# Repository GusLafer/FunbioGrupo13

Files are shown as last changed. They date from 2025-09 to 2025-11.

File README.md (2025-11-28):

Damas y caballeros, sean bienvenidos al respositorio del grupo 12 del curso "Fundamentos de Biodiseño" :3
# Fundamentos de Biodiseño Grupo 12
Integrantes:
* CASTILLO MAYTA, ANYELO ARMANDO, anyelo.castillo@upch.pe
* CASTILLO ZAPATA, CRISTHIAN LEONARDO, cristhian.castillo@upch.pe
* CERNA ACOSTA, JULIO ANDRES julio.cerna@upch.pe
* CUENTAS FERREÑAN, BONNIE CAMILA, bonnie.cuentas@upch.pe
* FERNANDEZ BACA LARA, GUSTAVO RODOLFO, gustavo.fernandez.baca@upch.pe
* GARCIA ROJAS, KARLA EMILY, karla.garcia.r@upch.pe

Logo del grupo

## Tabla de contenidos:
* Ficha de enfermedad
  * Nombre de la enfermedad: Esclerosis Lateral Amiotrófica
  * Sistema afectado: Neurologico
  * Breve descripcion: Enfermedad que se caracteriza por la degeneracion de las neuronas motoras, lo que causa debilidad en diferentes musculos.
* Factores y analisis de la enfermedad
* Prevención, diagnóstico, tratamiento y monitoreo

  Hay un unico medicamento, el riluzol, que demostro retrasar el uso de ventilacion mecanica.

   Entre sus metodos de diagnostico estan:

  * Neurofisiologia: por medio de la electromiografía con neuroconducciones se logran detectar alteraciones en la neurona Motora Inferior.  
  * Neuroimagenes: 
  * Estudios geneticos: 
  * Laboratorios: 
* Reflexión ingenieril:
  
  El prototipo consiste en una palanca mecánica adaptable que se acopla directamente al eje de la rueda de la silla de ruedas. Está diseñada específicamente para un paciente tetrapléjico con movilidad muy limitada en los brazos, que no puede alcanzar ni accionar el sobre-aro convencional.
  
* Bibliografia
  
  Zapata-Zapata, C., Franco-Dáger, E., Solano-Atehortúa, J., & Ahunca-Velásquez, L. (2016). Esclerosis lateral amiotrófica: actualización. IATREIA, 29(2). https://doi.org/10.17533/udea.iatreia.v29n2a08
  Ingre, C., Roos, P. M., Piehl, F., Kamel, F. y Fang, F. (2015). Factores de riesgo para la esclerosis lateral amiotrófica. Epidemiología clínica, 7, 181–193. https://doi.org/10.2147/CLEP.S37505

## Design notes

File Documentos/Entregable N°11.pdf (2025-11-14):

ENTREGABLE N° 11: INTEGRACIÓN HARDWARE - SOFTWARE - MANUFACTURA DIGITAL

1. Verificación del software
Funcionalidad | Cumplimiento | Observaciones/mejoras
SÍ | NO
La señal de encendido debe iniciar el sistema del microcontrolador y los demás componentes, incluido el LED de encendido | SI | | Como mejora, se podría usar un interruptor fácil de manipular por el usuario.
Se lee correctamente la posición del switch de cambio de sentido con 3 terminales | SI | | Asegurar que los cables estén bien sujetos.
El servomotor se mueve acorde a lo indicado con el switch de cambio de sentido. | SI | | El servo cumple con las funciones que se le asignaron correctamente.
Cuando se detecta una batería menor a 20% debe mandar una señal que encienda el LED de carga. | | NO | Se debe ajustar la lectura de voltaje para que se pueda encender un led por batería baja.
2. Verificación de hardware
Preguntas clave:
- ¿Cuánto peso debe tener el dispositivo?
El dispositivo no debe superar los 2 kg, para no agregar carga excesiva a la silla, ni dificultar el movimiento del usuario.
- ¿Qué altura y posición debe tener la palanca y el mango?
La palanca es ajustable, de modo que puede colocarse a la altura más cómoda para cada usuario sin generar esfuerzo adicional.
- ¿El dispositivo permite desplazarse en silla de ruedas?
Si. La palanca y el mecanismo están diseñados para asistir el avance de la silla de ruedas mediante un sistema de tracción controlado por servo.
- ¿Cuánta fuerza máxima debe ejercer el paciente para movilizarse?
La fuerza requerida no debe superar aproximadamente los 20N.
- ¿Dónde y cómo se debe acoplar el dispositivo en la silla de ruedas?
El dispositivo se acciona desde el eje de la rueda, mediante un mecanismo tipo ratchet asistido por un servo, que convierte el movimiento de la palanca en avance sin retroceso.
- ¿Dónde se deben ubicar los interruptores para que sean accesibles?
El interruptor debe colocarse cerca del mango de la palanca, accesible sin que el usuario deba perder el control.
- ¿Qué señales visuales debe brindar el dispositivo?
Es un prototipo, en un futuro se le incorporarán leds para que el usuario pueda tener señales visuales.
- ¿Cuánto tiempo debe durar la batería?
La batería debe permitir mínimo 2 horas continuas de uso antes de requerir carga

Esta debe tener por lo menos una duración de 2 horas

Requerimiento de diseño | Cumplimiento | Resultados/mejoras
SÍ | NO
El dispositivo pesa menos de 1 kg | | NO | Es un prototipo así que se podría mejorar mediante materiales y componentes más ligeros.
La altura de la palanca y la posición del mango son regulables basado en la ergonomía del paciente. | SI | | Se puede mejorar la rigidez para evitar pequeños movimientos laterales.
El mango es suave y cómodo para el usuario | | No | El dispositivo es un prototipo por lo cual no se priorizo que el mango sea suave sino el funcionamiento del sistema ratchet
El sistema ratchet permite el giro de la rueda en un sentido y el retroceso de la palanca en el otro | SI | | Se puede optimizar el servo Horn para un cambio de sentido más cómodo.
El usuario debe ejercer menos de 50 N para remar la silla mediante la palanca | SI | | El esfuerzo requerido está dentro del rango adecuado para el usuario.
El encaje del dispositivo se acopla con firmeza y estabilidad al eje de una silla de ruedas estándar | | No | El dispositivo por el momento no entra por completo al eje de la silla de ruedas, pero esta si puede mover la rueda, se busca regular la pieza para que esta se acople por completo en el eje de la rueda.
El dispositivo presenta un interruptor de encendido y uno de cambio de sentido del desplazamiento | SI | | El dispositivo cuenta con estas funciones aunque todavía falta colocar los dispositivos en lugares óptimos.
Los interruptores se encuentran cerca del mango para facilitar el acceso | | No | Estos por el momento no se encuentran en la parte del mango.
Los interruptores son fácilmente manipulables sin necesidad de movimientos finos. | | No | Se busca optimizar los interruptores para que el usuario pueda presionar los interruptores con facilidad
Hay leds ubicados en zonas visibles que indican el ON/OFF del dispositivo y cuando la batería debe ser recargada (<20%) | | No | Por el momento no se colocaron ciertos leds, ya que lo principal que se busco fue el correcto funcionamiento del sistema ratchet

La duración de la batería debe ser mínimo de 2 horas | | No | Optimizar el consumo de batería
La batería es recargable y presenta un puerto de carga accesible para su uso. | Si | | Mayor capacidad de batería

Fotos:

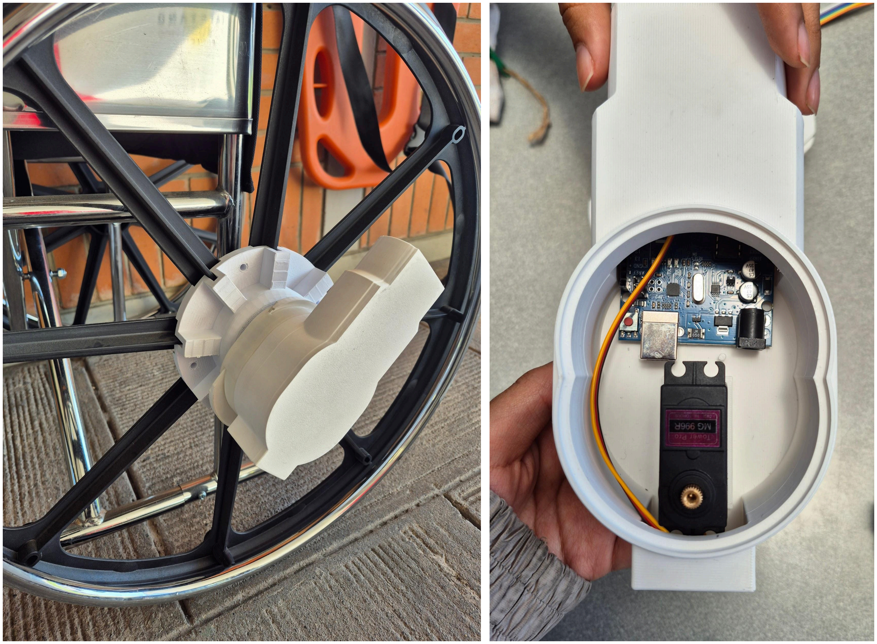
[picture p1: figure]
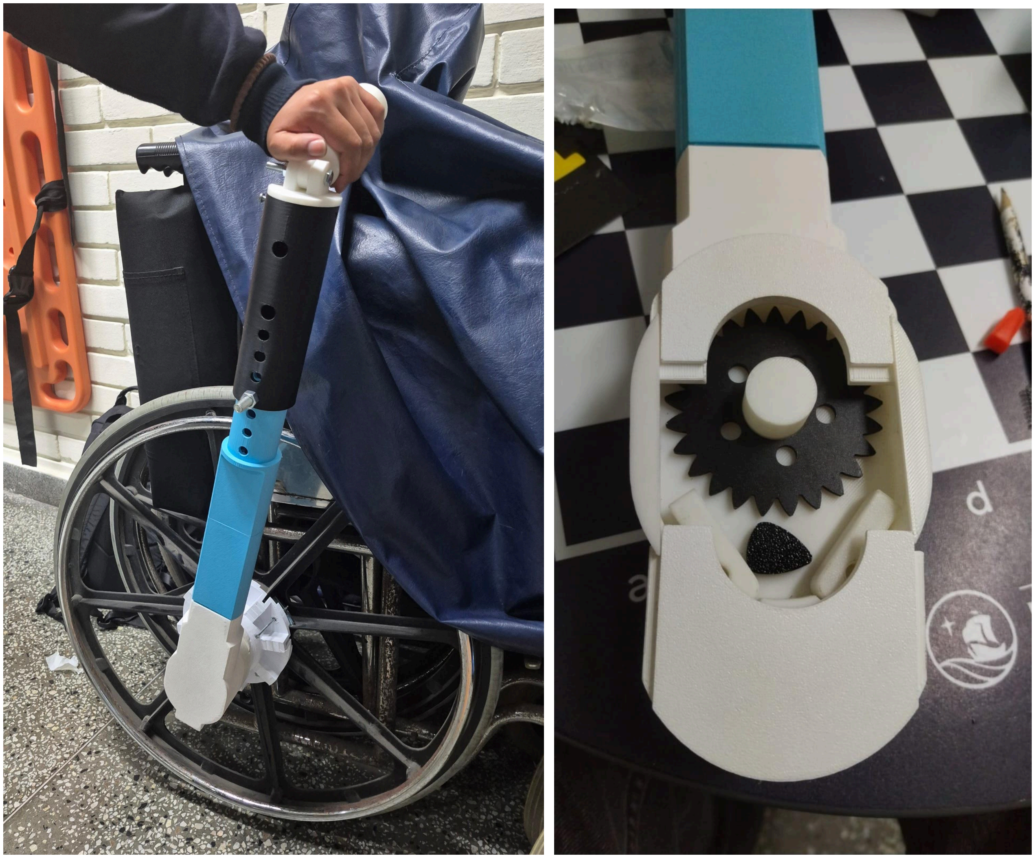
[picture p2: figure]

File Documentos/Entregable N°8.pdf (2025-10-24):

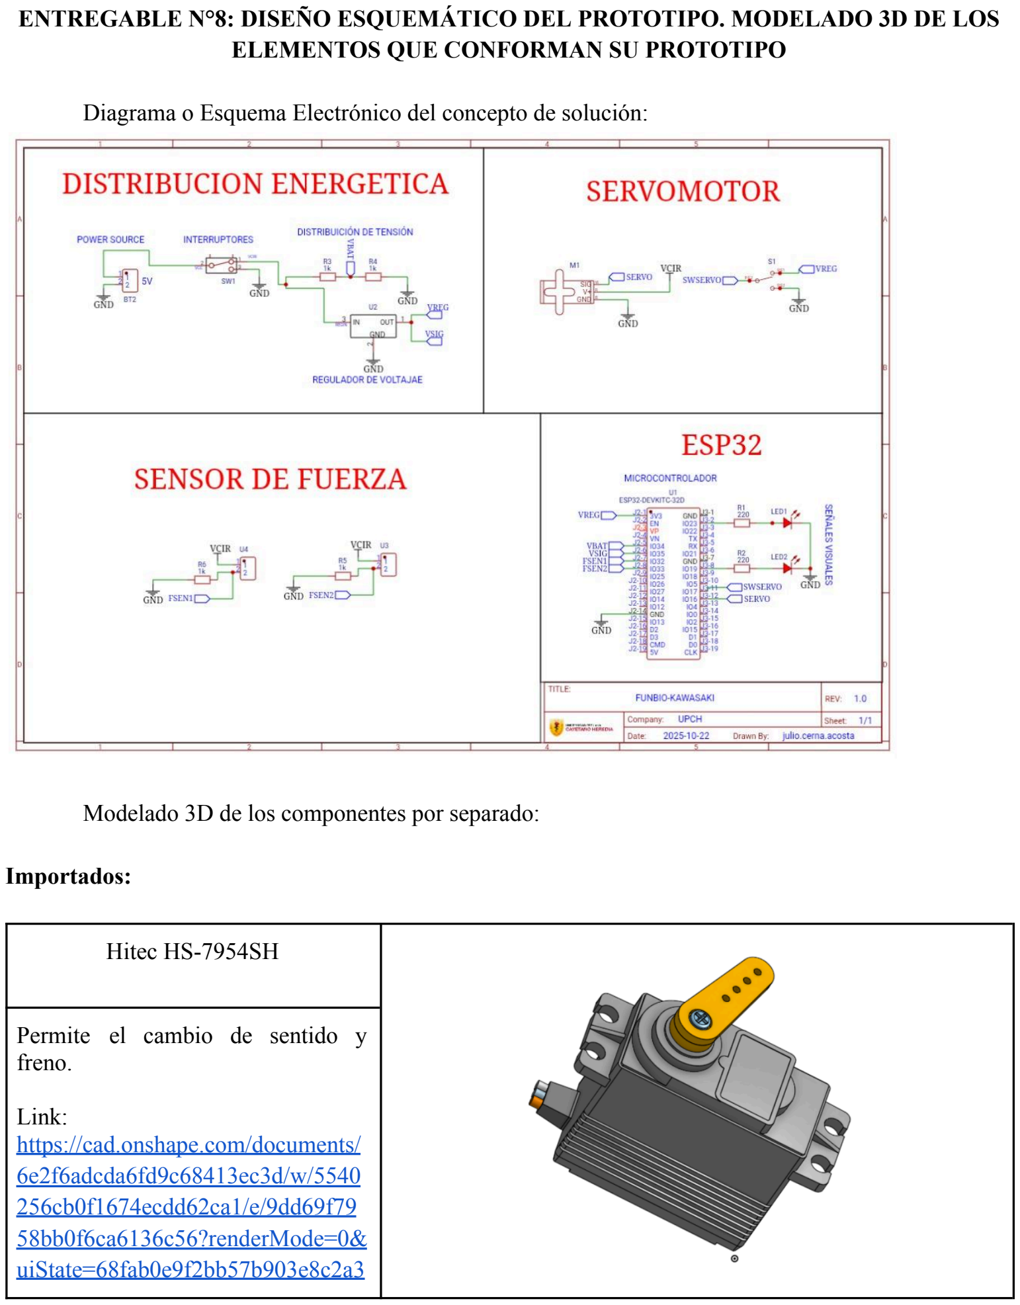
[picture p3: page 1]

ENTREGABLE N°8: DISEÑO ESQUEMÁTICO DEL PROTOTIPO. MODELADO 3D DE LOS ELEMENTOS QUE CONFORMAN SU PROTOTIPO

Diagrama o Esquema Electrónico del concepto de solución:

Modelado 3D de los componentes por separado:

Importados:

Hitec HS-7954SH

Permite el cambio de sentido y freno.

Link:
https://cad.onshape.com/documents/6e2f6adcda6fd9c68413ec3d/w/5540256cb0f1674ecdd62ca1/e/9dd69f7958bb0f6ca6136c56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 (https://cad.onshape.com/documents/6e2f6adcda6fd9c68413ec3d/w/5540256cb0f1674ecdd62ca1/e/9dd69f7958bb0f6ca6136c56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)

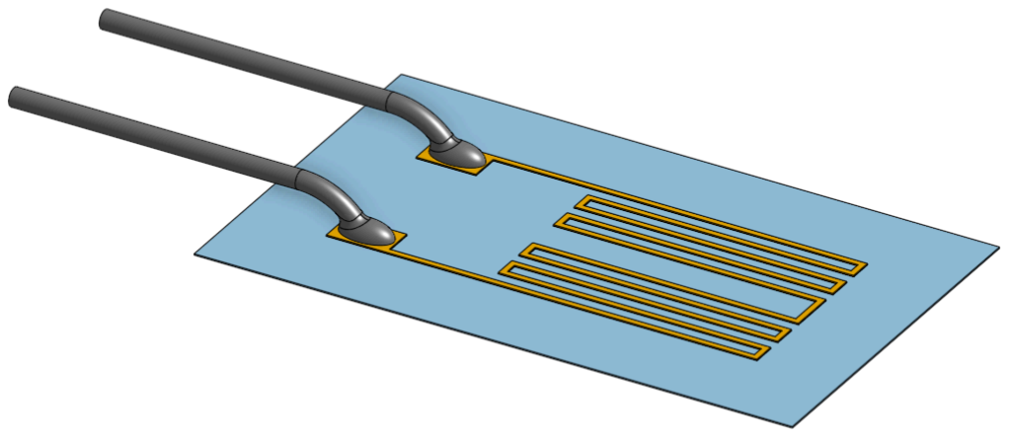
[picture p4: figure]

Strain gage

Link:
https://cad.onshape.com/documents/4b16e37327758734f3fa5df2/w/5c22215e732065d5cc922fd4/e/2bd44ea4c1119a9901e88b26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 03 (https://cad.onshape.com/documents/4b16e37327758734f3fa5df2/w/5c22215e732065d5cc922fd4/e/2bd44ea4c1119a9901e88b26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)

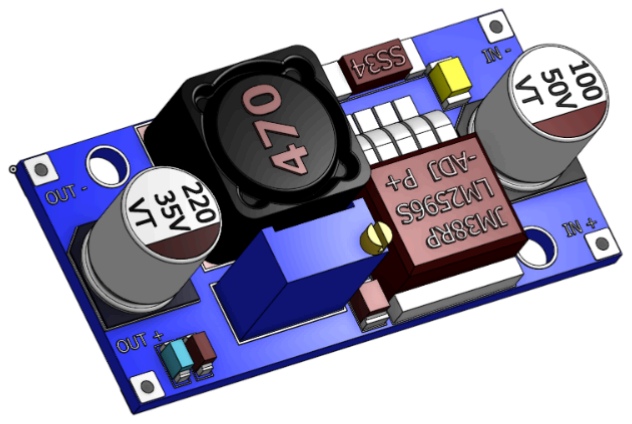
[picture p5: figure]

Regulador De Voltaje Dc-dc Lm2596

Link:
https://cad.onshape.com/documents/68f68d7b6ea87911dee5d4d5/w/26a8b8a100db7551ed4b5446/e/69e769439670035a26500c76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 4e (https://cad.onshape.com/documents/68f68d7b6ea87911dee5d4d5/w/26a8b8a100db7551ed4b5446/e/69e769439670035a26500c76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)

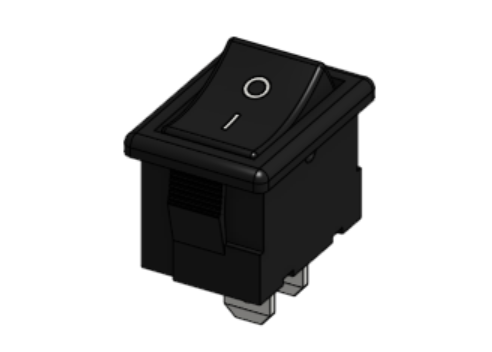
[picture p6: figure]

Switch

Link:
https://cad.onshape.com/documents/15d91f6365dc077cde08afb1/w/c799197fe858fa2fdd029811/e/91cf00b577ad0bc163d0bb50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 0 (https://cad.onshape.com/documents/15d91f6365dc077cde08afb1/w/c799197fe858fa2fdd029811/e/91cf00b577ad0bc163d0bb50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)

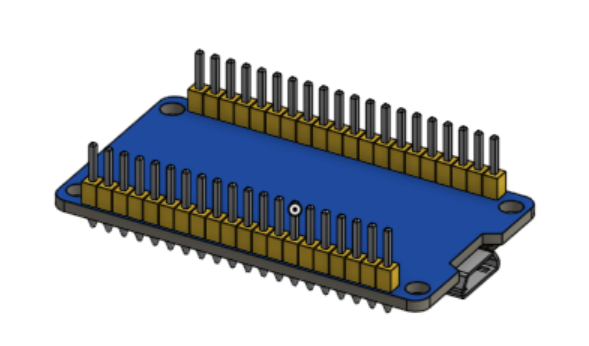
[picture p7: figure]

ESP32

Link:
https://cad.onshape.com/documents/bf06bb8bfbe8fe0004041b22/w/b9b77c645c58177d81bc9766/e/6baab793c940c2302ab8e6b1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 22 (https://cad.onshape.com/documents/bf06bb8bfbe8fe0004041b22/w/b9b77c645c58177d81bc9766/e/6baab793c940c2302ab8e6b1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)

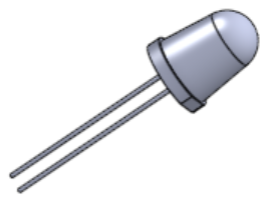
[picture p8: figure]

LED

Link:
https://cad.onshape.com/documents/37211811a02d1b124de81013/w/8628b6db9451a273728f0278/e/45fb6b6c64cf7a15e1a260d2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 2c (https://cad.onshape.com/documents/37211811a02d1b124de81013/w/8628b6db9451a273728f0278/e/45fb6b6c64cf7a15e1a260d2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)

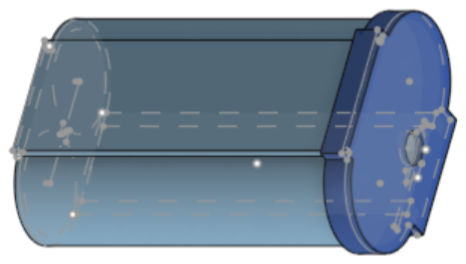
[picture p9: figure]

Bateria

Link:
https://cad.onshape.com/documents/bd390f73bad338591f4f21d5/w/d0b8a0cbc1fee8c218ad7ef2/e/fb711856eca25a9d5b222507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 (https://cad.onshape.com/documents/bd390f73bad338591f4f21d5/w/d0b8a0cbc1fee8c218ad7ef2/e/fb711856eca25a9d5b222507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)

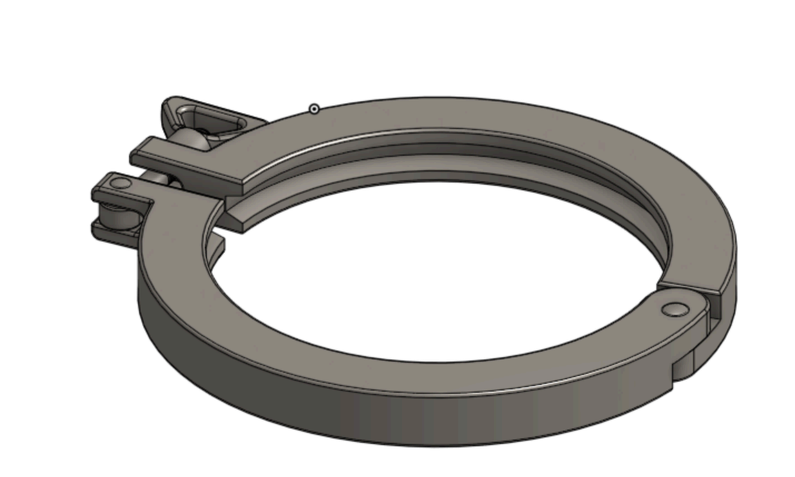
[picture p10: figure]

Abrazadera

Asegura ajuste al eje
Modificado a escala
Link:
https://cad.onshape.com/documents/deec412b3cd5b3ff2e335d65/w/e02b89dd3c5a9769be20eac2/e/080fca94275 5896d26315fad (https://cad.onshape.com/documents/deec412b3cd5b3ff2e335d65/w/e02b89dd3c5a9769be20eac2/e/080fca942755896d26315fad)

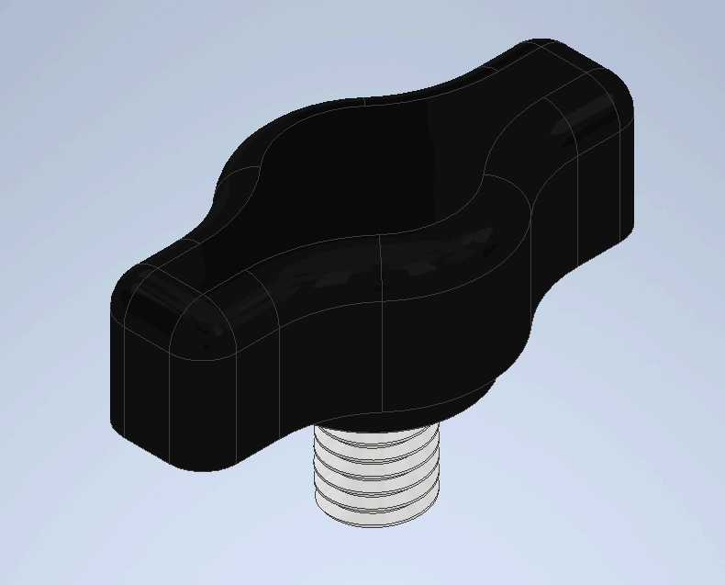
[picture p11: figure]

Tornillo mariposa

Asegura ajuste a la tapa
Modificado a escala y medidas Link:
https://cad.onshape.com/documents/ea362cc740fc813d504dcab4/w/2dfea8bfc239fe4eaefa0a0f/e/b6eb411fec96b 5a4a8f9950d (https://cad.onshape.com/documents/ea362cc740fc813d504dcab4/w/2dfea8bfc239fe4eaefa0a0f/e/b6eb411fec96b5a4a8f9950d)

Modelados:

Partes Ratchet:

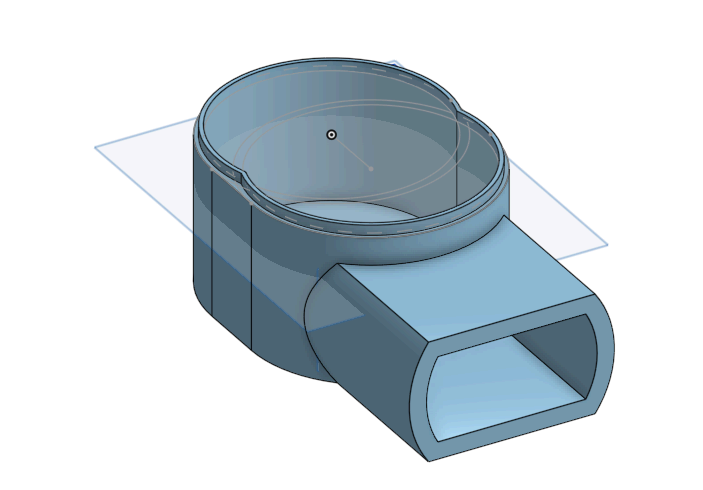
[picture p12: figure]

R_union_barra (v1)

Parte donde irá el servomotor y se unirá al ratchet y a la palanca

Link:
https://cad.onshape.com/documents/464e919604ea526d5648999a/w/d121562e4b88be7a7ad0b0e5/e/f0aebabd30336cdb6392c2f0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 7f (https://cad.onshape.com/documents/464e919604ea526d5648999a/w/d121562e4b88be7a7ad0b0e5/e/f0aebabd30336cdb6392c2f0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)

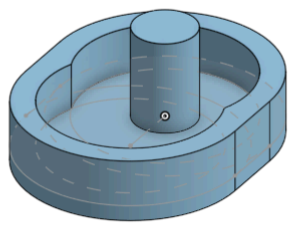
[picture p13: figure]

R_ratchet (v1)

Base del ratchet donde están las piezas y se unirá al eje.

Link:
https://cad.onshape.com/documents/45764cfabb6fb147acec867b/w/e1540424ae78a76a7e8f491d/e/372a0884e43dabc76ce558e3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 (https://cad.onshape.com/documents/45764cfabb6fb147acec867b/w/e1540424ae78a76a7e8f491d/e/372a0884e43dabc76ce558e3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)

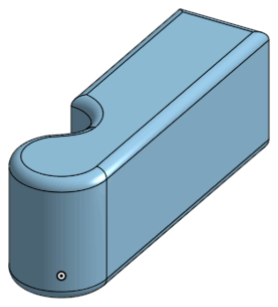
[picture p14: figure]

R_barra_dirección (v1)

Barras que moverán la dirección de empuje del ratchet

Link:
https://cad.onshape.com/documents/abc4462441bd8285f640b40b/w/0deaff2bca6a559aade33c1c/e/dc0393127c02d3c945c542dd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 2b (https://cad.onshape.com/documents/abc4462441bd8285f640b40b/w/0deaff2bca6a559aade33c1c/e/dc0393127c02d3c945c542dd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)

Partes agarre:

Partes palanca:

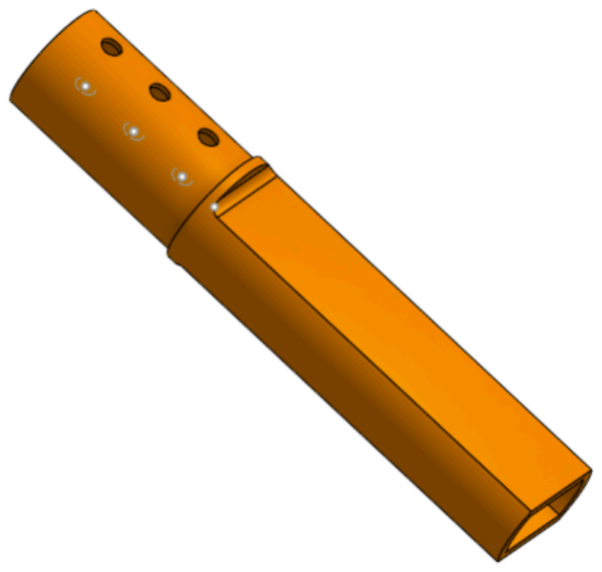
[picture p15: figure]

P_union_inferior (v1)

Parte baja de la palanca unida al ratchet. Permite regulación de altura.

Link:
https://cad.onshape.com/documents/2f84863571458f0843a0e98b/w/9121a1c4954e7fdb289b565d/e/7242b37608cc31b0d9007e25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 85 (https://cad.onshape.com/documents/2f84863571458f0843a0e98b/w/9121a1c4954e7fdb289b565d/e/7242b37608cc31b0d9007e25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)

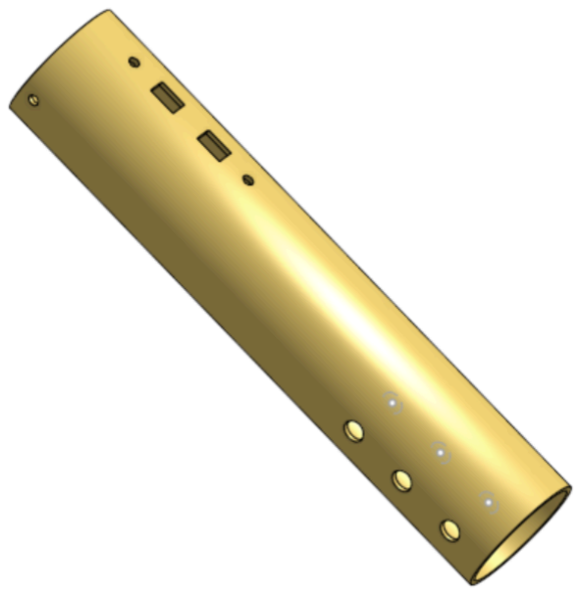
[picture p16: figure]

P_union_superior (v1)

Zona de la palanca donde se ubican los switches y los leds. Permite la regulación de altura y rotación de mango.

Link:
https://cad.onshape.com/documents/e227e86888257dc4c6b97535/w/28939abc9edbdbd3414ac3fe/e/0bb11ebb1a3570102df3bdb7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 (https://cad.onshape.com/documents/e227e86888257dc4c6b97535/w/28939abc9edbdbd3414ac3fe/e/0bb11ebb1a3570102df3bdb7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)

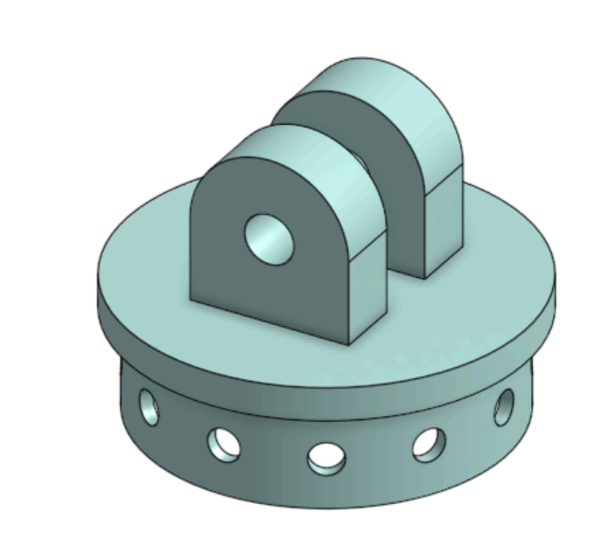
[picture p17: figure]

P_rotador_mango (v1)

Une la palanca y el mango. Permite la rotación de mango.

Link:
https://cad.onshape.com/documents/7d2f22928c483819d20c5e3c/w/b9eb8ec4634620f00a2cbebe/e/34b27d08f3bdd8d822e492ca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 (https://cad.onshape.com/documents/7d2f22928c483819d20c5e3c/w/b9eb8ec4634620f00a2cbebe/e/34b27d08f3bdd8d822e492ca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)

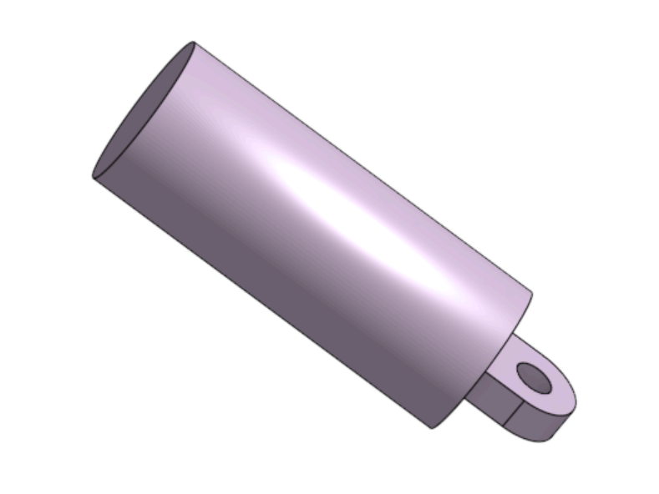
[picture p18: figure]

P_mango (v1)

Permite rotación.

Link:
https://cad.onshape.com/documents/af7af84edcc4210f90f5378e/w/b941605ff2f3a997c7821142/e/30602ade613951220c3a4cd7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 (https://cad.onshape.com/documents/af7af84edcc4210f90f5378e/w/b941605ff2f3a997c7821142/e/30602ade613951220c3a4cd7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)

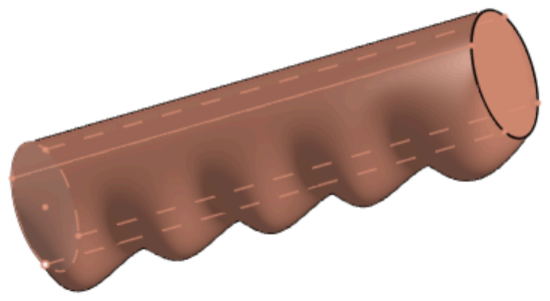
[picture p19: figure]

P_cobertor (v1)

Crea un agarre suave y ergonómico

Link:
https://cad.onshape.com/documents/b78cc6f91561b2d188f7f562/w/9ff4459ed0ff59a79d59c498/e/2f46d9a5d931a0cf177a3091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 (https://cad.onshape.com/documents/b78cc6f91561b2d188f7f562/w/9ff4459ed0ff59a79d59c498/e/2f46d9a5d931a0cf177a3091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)

Partes acoplamiento al eje

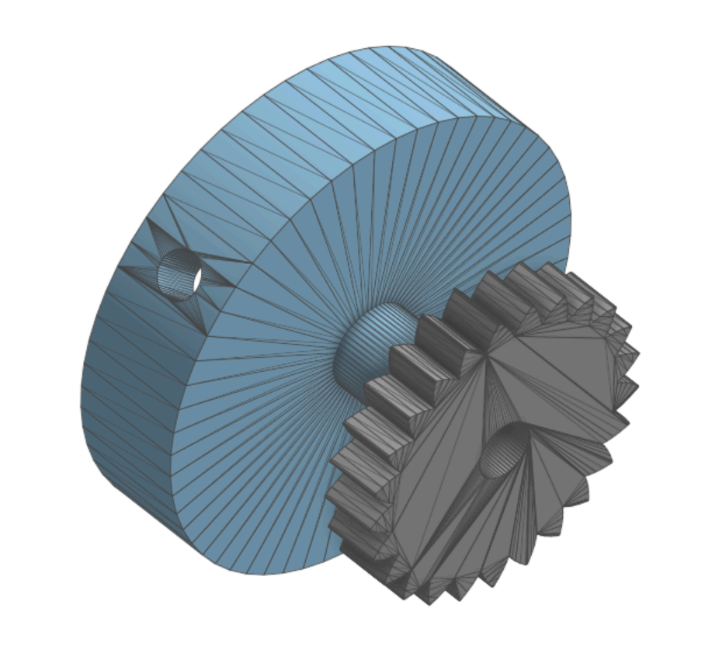
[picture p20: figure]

A_tapa (v1)

Personalizado al eje recubierto de la rueda

Link:
https://cad.onshape.com/documents/a5c98efa6c071a4eebbc048e/w/3d317df3e005d84f7e47620e/e/20bd107c268 293152c4c139c (https://cad.onshape.com/documents/a5c98efa6c071a4eebbc048e/w/3d317df3e005d84f7e47620e/e/20bd107c268293152c4c139c)

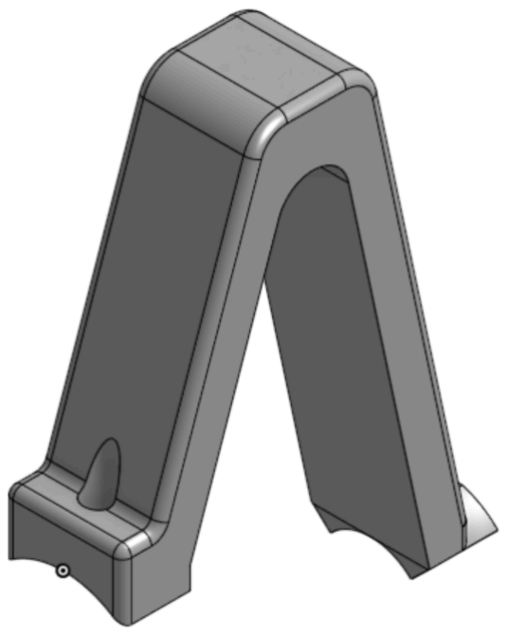
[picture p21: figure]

A_garra (v1)

Asegura la tapa apoyándose del eje metálico interior de la rueda
Link:
https://cad.onshape.com/documents/965c7bbaa5092d47b4f74c1a/w/ca38252d5423931be1847231/e/5ad22a763 afce963306b1131 (https://cad.onshape.com/documents/965c7bbaa5092d47b4f74c1a/w/ca38252d5423931be1847231/e/5ad22a763afce963306b1131)

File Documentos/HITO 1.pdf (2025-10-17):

# KAWAZAKI

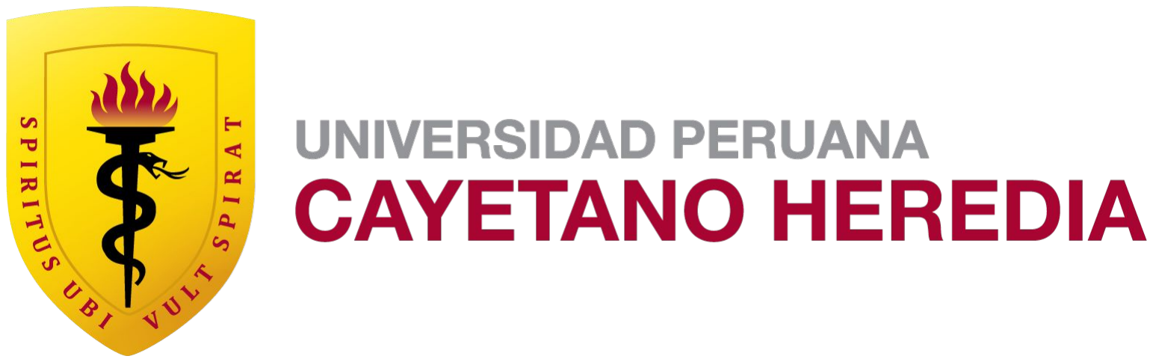
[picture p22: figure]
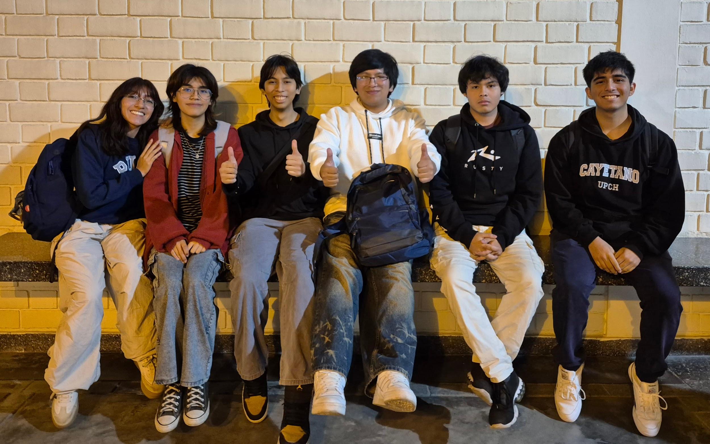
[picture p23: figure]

Integrantes - Anyelo Castillo Mayta - Encargado de sistemas - Leonardo Castillo Zapata - Encargado electrónica - Julio Cerna Acosta - Encargado programación - Bonnie Cuentas Ferreñan - Encargada organización - Gustavo Fernandez Baca Lara - Diseñador industrial - Karla García Rojas - Encargada mecanismos

# Grupo 12

Análisis del Caso | Una lesión medular traumática implica un daño en
| cualquier parte de la médula espinal. También

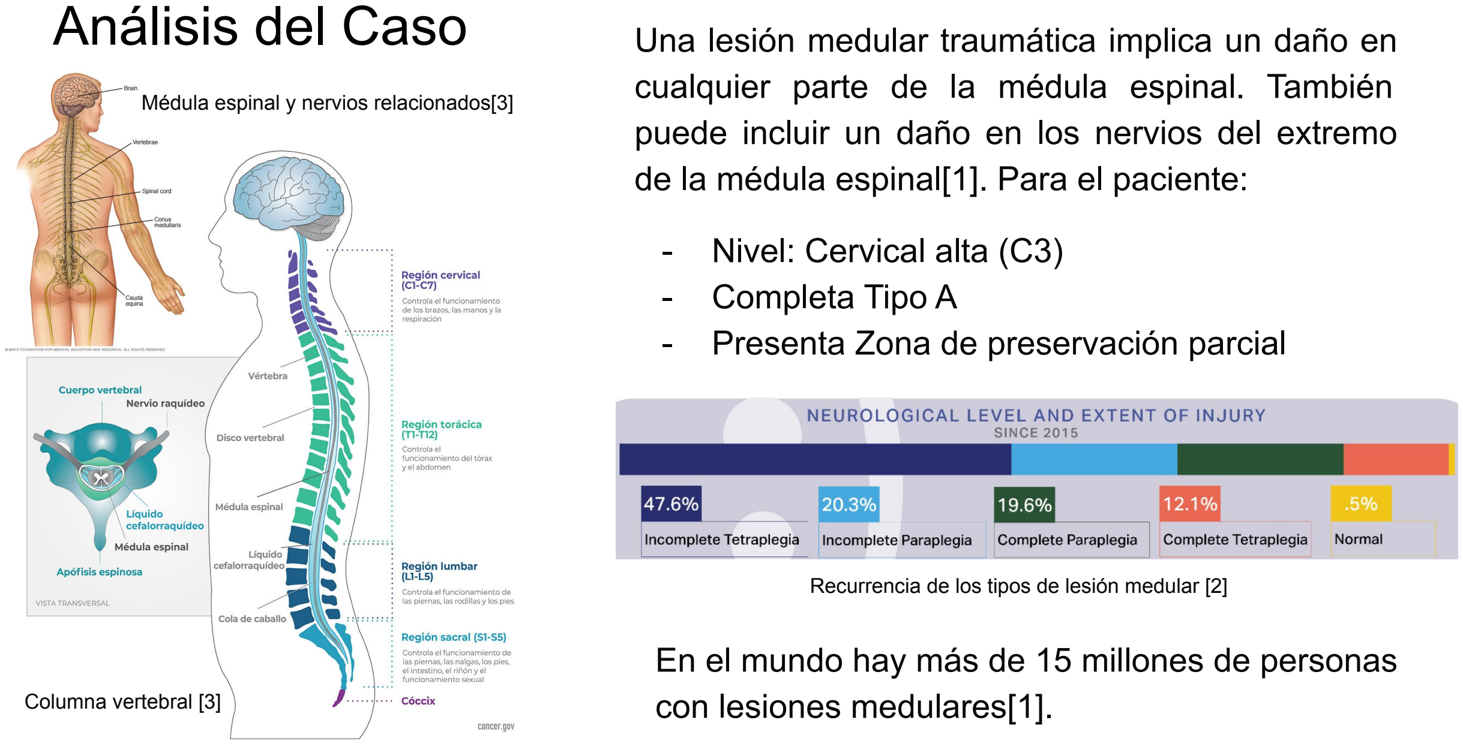
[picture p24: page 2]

## puede incluir un daño en los nervios del extremo de la médula espinal[1]. Para el paciente:

## - Nivel: Cervical alta (C3) - Completa Tipo A - Presenta Zona de preservación parcial

## En el mundo hay más de 15 millones de personas

con lesiones medulares[1].

Recurrencia de los tipos de lesión medular [2]

Columna vertebral [3]

Médula espinal y nervios relacionados[3]

# Análisis del Caso


## Posibles complicaciones[3]:

## - Existe un gran riesgo de desarrollar úlceras por presión - Algunas personas con lesiones de la

médula espinal experimentan espasticidad.

## Otras personas, pueden perder tono

muscular, lo que se conoce como flacidez.

## - La movilidad limitada puede derivar en aumentar de peso y desarrollar

enfermedades cardiovasculares y diabetes.

Análisis del Caso; Solo el 3%; en algunos países de bajos ingresos tienen acceso a los productos de apoyo que necesitan; veces mayor dependiendo del país

Según estudios una mayor capacidad de movimiento se asocia con menos depresión [5]

Los adultos con lesiones medulares se enfrentan tasas de desempleo superiores al 60% y presentan tasa de mortalidad hospitalaria casi 3

## Según el Informe mundial de la OMS y el UNICEF sobre la tecnología de asistencia

# Estado del Arte

Nombre | Descripción funcional | Ventajas | Desventajas | Imagen


Wheelchair with Ratchet/Pawl Drive System (2020) [6] | Sistema acoplable con mecanismo ratchet, palancas laterales y selector F–N–R que permite avanzar, retroceder o frenar. | • Permite avance, reversa y frenado en un mismo sistema. • No necesita batería ni motor. • Compatible con usuarios sin agarre (usa correas). | • Selector F–N–R puede ser difícil de accionar sin dedos. • Componentes de precisión aumentan el costo.


Wheelchair with Lever Drivetrain (2014) [7] | Sistema de propulsión por palancas y cadena con rueda libre, que permite avanzar sin retroceso y frenar desde la misma palanca, con tracción independiente por rueda para facilitar la dirección. | •Alta eficiencia y control individual por rueda. •Mecanismo de cadena robusto y reemplazable. •Freno integrado en la palanca. | •Requiere mantenimiento y lubricación frecuente. •Algo ruidoso y pesado.


Electric attachable/de tachable device for wheelchairs (2018) [8] | Sistema eléctrico acoplable que se instala en una silla manual, incorporando un módulo con motor y batería que impulsa las ruedas traseras mediante engranajes, permitiendo al usuario desplazarse sin esfuerzo físico. | • Fácil conversión a modo eléctrico • Mayor autonomía del usuario • Asistencia completa sin esfuerzo físico. | • Depende de batería • Mayor peso y costo •Requiere mantenimiento eléctrico.

### Nombre Descripción funcional

Ventajas | Desventajas | Imagen


NuDrive Air –
Lever-Drive
Propulsion
System [9]

Sistema mecánico
acoplable con palancas
laterales que impulsan
las ruedas mediante un
mecanismo de reducción
y embrague, permitiendo
avanzar, frenar o
retroceder sin necesidad
de agarre manual.
- Reduce esfuerzo hasta 40 %
- Protege hombros y
muñecas
- fácil de acoplar y usar.
- Aumenta el peso
total
- Requiere
movilidad del
brazo y
mantenimiento
periódico.

GRIT
Freedom
Chair 3.0
–Lever-Drive
Wheelchair
[10]

Silla todo terreno con
palancas largas
conectadas a un sistema
de transmisión tipo
bicicleta, que permite
desplazarse por grava,
tierra, nieve o barro con
menor esfuerzo y alta
estabilidad.
- Gran tracción y control
- Fácil desmontaje y
transporte
- Mantenimiento sencillo con piezas comunes
- Frenos ajustables.
- Mayor peso y
tamaño
- Requiere
movilidad activa
de brazos
- Puede necesitar
correas de
sujeción para
usuarios sin
prensión.


# Metodología VDI

## Propuesta de solución:

## Sistema de propulsión mediante palancas con mecanismo ratchet para sillas de ruedas, dirigido a pacientes cuadripléjicos con movimiento residual en extremidades superiores. El dispositivo transforma la fuerza de brazos del paciente en desplazamiento de la silla mediante amplificación mecánica y


## sistema unidireccional

REQUERIMIENTOS FUNCIONALES | REQUERIMIENTOS NO FUNCIONALES

Exigentes:
- Propulsión mediante sistema de remado con
palancas
- Transformación de fuerza residual en energía mecánica
- Sistema de frenado seguro
- Acople a silla de ruedas estándar
- Control sensible de movimientos del usuario
- Sistema de bloqueo total para reposo

Exigentes:
- Adaptación a dimensiones antropométricas
- Ergonomía para evitar lesiones
- Sujeción firme durante todo el uso
- Soportar fuerza ejercida sin deterioro
- Componentes con disponibilidad garantizada
- Facilidad de uso con curva de aprendizaje mínima
- Portabilidad mediante acople/desacople
Importantes: ● Freno eléctrico activado por señal del usuario ● Sensor de fuerza para medición de capacidad del paciente. ● Mecanismo de desacople fácil y seguro | Importantes: ● Componentes duraderos con mínimo mantenimiento ● Piezas reemplazables independientemente ● Costos de inversión y mantenimiento accesibles ● Capacitación única y sencilla para familiares ● Aceptación social y cultural


Deseables: ● Botón de pánico automático ● Ajuste personalizado de medidas ● Actualización de software manual | Deseables: ● Diseño estético integrado a la silla ● Materiales de bajo impacto ambiental ● Diferenciación competitiva en mercado

Funciones del Sistema; ENTRADA; SALIDA; Energía • Fuerza muscular residual (brazos) • Energía eléctrica (freno/sensores); PROCESAMIENTO; Captar movimiento Recibir desplazamiento de palancas; automática

Energía
• Energía mecánica
rotacional
• Movimiento lineal de la
silla

Registrar fuerza aplicada
Sensor de fuerza para monitoreo
de progreso temporal

Información
• Intención de movimiento
• Comando de frenado
• Fuerza ejercida (para registro
de progreso)

Convertir a rotación
Sistema ratchet unidireccional

• Retroalimentación
• Datos de fuerza aplicada
• Estado del sistema
(avance/retroceso/freno)

Retornar palanca
Resortes de recuperación

# Black box

Energía mecánica; Energía eléctrica; Señal encendido; Señal usuario; Energía cinética; Datos métricos

# Esquema de funciones


# Matriz morfológica

Funciones | 1 | 2
Accionar sistema de empuje | Palanca en el eje de rotación | Palanca en el chasis
Amplificar fuerza ejercida | Torque por palanqueo | Sistema de poleas
Regular energía | Reguladores lineales ajustables | lineales fijos
Energizar | Pila de litio | Power bank
Transmitir señal de cambio | Switches | Botones
Mover sistema de rotación | Movimiento mecánico | Rotación por servomotor
Cambiar de dirección de movimiento | Sistema Ratchet | Sistema en base a fricción
Sensar fuerza | Strain Gauge | Células de carga
Transmitir información | Arduino y WIFI ESP8266 | ESP32
Procesar datos | Aplicación | Web

# Bocetos


# Siguientes pasos

Concluimos que el diseño de una palanca la cual sea capaz de implementarse a la silla de ruedas y a su vez sensar la fuerza que ejerce para poder moverse es relevante para un estudio del progreso del paciente en su rehabilitación, además de cuantificar la mejora gracias a la adaptación de silla de ruedas. Por otro lado el siguiente paso a desarrollar de nuestra propuesta solución es la implementación de un acelerómetro para poder tener datos más exactos para su evaluación, de

igual manera la implementación de las tecnologías en la palanca.


# Referencias

[1] Organización Mundial de la Salud, "Lesión de la médula espinal," Centro de prensa, 16 de abril de 2024. [En línea]. Disponible: https://www.who.int/es/news-room/fact-sheets/detail/spinal-cord-injury
[2] National Spinal Cord Injury Statistical Center, Traumatic Spinal Cord Injury Demographics at a Glance 2025. Birmingham, AL: University of Alabama at Birmingham, 2025. https://bpb-us-w2.wpmucdn.com/sites.uab.edu/dist/f/392/files/2025/02/Traumatic-SCI-Infographic-Demographics-at-a-Glance-2025.png
[3] | Mayo | Clinic, | "Lesión | de | la | médula | espinal," | Nov. | 07, | 2024. | [En | línea]. | Disponible:
https://www.mayoclinic.org/es/diseases-conditions/spinal-cord-injury/symptoms-causes/syc-20377890
[4] Organización Mundial de la Salud y Fondo de las Naciones Unidas para la Infancia, Informe mundial sobre la tecnología de asistencia. Ginebra: OMS y UNICEF, 2022. [En línea]. Disponible: https://www.who.int/publications/i/item/9789240049451
[5] Z. Khazaeipour et al., "Depression following spinal cord injury: Its relationship to demographic and socioeconomic indicators," Top. Spinal Cord Inj. Rehabil., vol. 21, no. 2, pp. 149-155, 2015, doi: 10.1310/sci2102-149.
[6] US 10,617,580 B2 – Wheelchair with Ratchet/Pawl Drive System, U.S. Patent, 2020. Disponible en: https://patents.google.com/patent/US10617580B2/en
[7] US 8,844,959 B2 – Wheelchair with Lever Drivetrain, U.S. Patent, 2014. Disponible en: https://patents.google.com/patent/US8844959B2/en
[8] EP 3409254 A1 – Electric Attachable/Detachable Device for Wheelchairs, European Patent, 2018. Disponible en: https://patents.google.com/patent/EP3409254A1/en
[9] | NuDrive | Air | – | Lever-Drive | | Propulsion | System, | André | | Viger, | 2024. | Disponible | en:
https://andreviger.com/en/manual-wheelchair-accessories/790-nudrive-air-wheelchair-propulsion-lever-system.html
[10] GRIT Freedom Chair 3.0 – Lever-Drive Wheelchair, GRIT USA, 2024. Disponible en: https://www.gogrit.us/grit-freedom-chair-3-0/

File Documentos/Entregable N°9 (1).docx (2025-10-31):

ENTREGABLE N°9: MODELADO 3D/AVANCE PROTOTIPADO ELECTRÓNICO.PLAN DE USABILIDAD BASADO EN EVIDENCIAS

Hardware Electronico

Software

Fabricación digital

Prototipo completo:


Planos:

Parte Ratchet


Parte Agarre


Parte Palanca


Plan de usabilidad basado en evidencias

Contexto de uso:

El dispositivo está pensado para el paciente Palacios, quien busca recuperar parte de su independencia en la movilidad diaria. Su entorno principal es el Instituto Nacional de Rehabilitación, donde realiza terapias y evaluaciones periódicas, aunque también se espera su uso en espacios domésticos adaptados, como su hogar, pasillos interiores o patios con superficie estable. La silla de ruedas con palanca ajustable está diseñada para aprovechar el movimiento residual de sus brazos y hombros, permitiéndole desplazarse con menor esfuerzo físico y sin requerir asistencia constante. Su uso sería frecuente y prolongado, tanto en sesiones de rehabilitación como en actividades cotidianas simples. Un cuidador o fisioterapeuta podría ayudar con ajustes iniciales del dispositivo o con el posicionamiento del paciente, pero la meta principal es que el usuario pueda accionar la palanca y controlar su desplazamiento de forma independiente, promoviendo su autonomía.

Perfil de usuario:

El paciente Palacios, sufrió una lesión medular en la vértebra C3 tras un accidente de tránsito, lo que le generó una cuadriplejia completa (grado A). A pesar de su condición, conserva cierta movilidad en los brazos y hombros gracias a una zona de preservación parcial (ZPP), lo que le permite realizar movimientos de empuje. No tiene control del tronco ni de las piernas, por lo que depende del apoyo de cuidadores para la mayoría de sus actividades diarias. En cuanto a sus capacidades cognitivas, el paciente se mantiene completamente lúcido. Durante la entrevista se mostró motivado y con gran interés en recuperar parte de su independencia, especialmente en actividades que le permitan sentirse en control de su entorno. Poder desplazarse por sus propios medios no solo representa una mejora funcional, sino también un logro personal que impacta directamente en su autoestima y bienestar emocional.

Análisis de tareas:

Tarea | Descripción | Tipo (Primer uso, Uso cotidiano, Mantenimiento) | ¿Crítica? | Justificación
Posicionar la silla de ruedas | Ubicar la silla en un espacio adecuado para el montaje inicial | Primer uso | No | Tarea sin el usuario encima.
Sujetar el dispositivo al eje de las ruedas | Acoplar el mecanismo ratchet al eje de la rueda y fijar la estructura a las barras de la silla | Primer uso | Si | Un mal acoplamiento impide el movimiento de la silla y podría llegar a causar desgaste acelerado de las piezas o desprenderse de la silla ocasionando que no se pueda frenar.
Ajustar largo de palanca | Regular la longitud de la varilla según ergonomía del paciente | Primer uso | No | Afecta comodidad pero no seguridad inmediata
Colocar correas de sujeción | Fijar las correas de tela resistente en la mano del usuario | Primer uso y uso cotidiano | Si | Su deslizamiento puede provocar pérdida de contacto con la palanca y desplazamientos involuntarios o caídas.
Capacitación para su uso | Comprender funcionamiento del controlador de rotación (avance/retroceso/inmóvil) | Primer uso | No | Importante pero se refuerza con práctica supervisada
Verificar posición del selector | Confirmar visualmente si está en avance, retroceso o inmóvil antes de propulsar | Uso cotidiano | Si | Una dirección incorrecta puede causar movimientos inesperados, colisiones o pérdida de control
Cambiar selector a dirección deseada | Manipular el controlador de rotación según movimiento a realizar | Uso cotidiano | Si | Cambio incorrecto resulta en desplazamiento opuesto al deseado, con riesgo de accidentes
Ejecutar movimiento de palanca | Realizar empuje repetitivo hacia adelante para propulsar la silla | Uso cotidiano | No | Acción principal pero protegida por topes mecánicos
Cambiar a modo inmóvil para detenerse | Activar posición de frenado del selector antes de desacoplarse | Uso cotidiano | Si | No hacerlo puede resultar en movimiento de la silla sin control del usuario al soltar las correas
Desacoplar correas | Liberar las manos de las correas de sujeción al finalizar | Uso cotidiano | No | Tarea final sin riesgo si el modo inmóvil está activado
Revisar estado de resortes | Inspeccionar periódicamente el funcionamiento de los resortes de retorno | Mantenimiento | Sí | Resortes desgastados impiden el retorno automático de la palanca, afectando seguridad
Verificar y lubricar mecanismo ratchet | Comprobar encaje correcto y aplicar lubricación preventiva | Mantenimiento | Sí | Mecanismo sin lubricación puede "saltar" o no acoplar, impidiendo transmisión de movimiento
Inspeccionar engranajes y piezas de tope | Verificar desgaste de componentes de acero del sistema | Mantenimiento | Si | Mecanismo sin lubricación puede "saltar" o no acoplar, impidiendo transmisión de movimiento

Criterios de éxito:

Para validar la usabilidad y funcionamiento de nuestro sistema de tracción asistida para un paciente con lesión medular a nivel C3, definimos criterios que permitirán verificar si el dispositivo cumple con los requisitos mínimos de eficacia, seguridad y facilidad de uso.

Criterio | Característica / Métrica Objetiva
Eficacia | El usuario debe lograr activar el modo de tracción en menos de 2 intentos y completar el movimiento de avance sin asistencia externa.
Eficiencia | La acción de activar/desactivar el sistema mediante el switch debe realizarse en menos de 2 segundos y sin requerir movimientos finos de los dedos.
Satisfaccion del usuario | El usuario debe indicar que se siente cómodo usando el sistema y que lo entiende bien, con una calificación de 4 de 5 o más en una escala simple de comodidad y facilidad de uso.
Seguridad | Durante el uso no deben ocurrir fallas del mecanismo de rachet (0 trabas), ni riesgos mecánicos (0 lesiones), y el sistema debe ser capaz de soportar su uso.
Comprensibilidad | El usuario debe identificar correctamente el modo TRACCIÓN o LIBRE mediante el LED con una tasa de acierto ≥ 90%.
Esfuerzo físico | La fuerza necesaria en las palancas no debe superar aproximadamente los 20 N, para ser compatible con la fuerza máxima generada por un paciente con lesión C3. [1]

REFERENCIAS:

[1] H. Hoffman, T. Sierro, T. Niu, M. E. Sarino, M. Sarrafzadeh, D. McArthur, V. R. Edgerton, and D. C. Lu, “Rehabilitation of hand function after spinal cord injury using a novel handgrip device: a pilot study,” Journal of NeuroEngineering and Rehabilitation, vol. 14, no. 1, Art. no. 22, Mar. 2017, doi: 10.1186/s12984-017-0234-1.

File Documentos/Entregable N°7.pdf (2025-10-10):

ENTREGABLE N°7: METODOLOGÍA VDI - PARTE 2

Modelos y Principios de solución Caja negra:


Esquema de funciones:


Matriz morfológica:

Funciones / Propuestas | 1 | 2
Sistema de empuje | Palanca implementada con un sistema ratchet que se adapta al eje de una silla de ruedas convencional. | Implementación de un sistema de poleas unido a las ruedas de la silla.
Amplificación de fuerza | Acción del sistema a cierta distancia del eje para aumentar el efecto del “palanqueo” | Uso de pistones hidráulicos para impulsar el giro del sistema de poleas.
Sistema de frenado | Frenado por cambio de dirección dirigida por mecanismo interno | Frenado por acción de la fricción con pastillas o pinzas

Tabla de valoración:

Criterios | 1 | 2
Facilidad de uso (colocación, ajuste) | 5 | 5
Portabilidad/peso | 5 | 5
Costo de tecnología | 4 | 3
Costo de operación | 4 | 4
Viabilidad de fabricación local | 5 | 3
Seguridad | 5 | 5
Tamaño/Integración | 5 | 3
Nivel de innovación | 3 | 5
Disponibilidad de repuestos | 4 | 4
Posibilidad de automatización | 5 | 4
Durabilidad de exteriores | 4 | 2
Complejidad | 3 | 5
Grado de contaminación | 5 | 4
Fácil mantenimiento | 5 | 3
Número de piezas | 4 | 2
TOTAL | 66 | 57

Espacio de solución

Boceto 1: | Dibujado por: Bonnie Cuentas Vista general del dispositivo integrado a silla de ruedas estándar


Descripción funcional:
El boceto muestra el acople del dispositivo en una silla de ruedas estándar. Se hace énfasis en el diseño de la palanca, la cual presenta 3 partes principales. La zona de agarre, la zona de regulación de largo y las correas de sujeción.
Pieza | Nombre | Material
1 | Agarre | Goma suave
2 | Correa | Tela resistente
3 | Varilla regulable | Metal (aluminio)

Boceto 2: | Dibujado por: Bonnie Cuentas Mecanismo de rotación del eje de la rueda con sistema Ratchet


Descripción funcional:
El boceto muestra el funcionamiento interno del dispositivo para mover el eje de la rueda. Se usa una pieza de control (con movilidad disponible para el usuario) que fija o no las piezas de tope unidas a resortes. En caso que se fije solo una pieza de tope, el resorte permitirá el movimiento del engranaje únicamente hacia un lado. Dependiendo de la pieza fijada se podrá avanzar o retroceder. Si ambas piezas de tope quedan libres, el resorte quedará completamente impedido de movimiento.
Pieza | Nombre | Material
1 | Pieza de tope x2 | Acero
2 | Controlador rotación | Acero
3 | Engranaje | Acero
4 | Resortes | Acero

Boceto 3: | Dibujado por: Gustavo Fernandez Baca Vista general del dispositivo con mecanismos integrados


Descripción funcional:
El boceto muestra el dispositivo acoplado a la silla de ruedas con los mecanismos funcionales. Se hace énfasis en el diseño de la palanca y su retroceso mediante un sistema de pistones; por otro lado el funcionamiento del eje de la palanca con mecanismos de engranaje planetario, matraca y diseño de pinzas para el agarre con la rueda.
Pieza | Nombre | Material
1 | Palanca principal | Acero
2 | Piston | Acero
3 | Matraca | Acero
4 | Pinzas | Acero
5 | Engranaje planetario | Acero

¿Fabricar o adquirir? / Técnicas de producción

Pieza | Obtención | Material | Técnica
Agarre | Fabricado | Goma espuma | Fabricación manual.
| | Silicona | Mediante molde y vaciado.
Varilla regulable | Adquirido | Aluminio | Se puede buscar piezas estándar que cumplan las relaciones métricas necesarias, o se pueden mandar a hacer
Resortes | Adquirido | Acero
Pieza de tope Controlador de rotación Engranaje (*) | Adquirido (producto) | Acero
| Fabricado (prototipado) | PLA / PETG | Mediante impresión 3D FDM, para lo cual se necesitan los modelados.
Correa | Fabricado | Tela | Fabricación manual.
Tornillos/pernos | Adquirido | - | -

(*Para estas piezas se están planteando 2 opciones: uno para el prototipado que requiere una producción rápida y económica para facilitar la iteración, y otro del producto donde se requerirían materiales resistentes y de calidad por el uso diario que se plantea para el producto.)

Secuencia de procesos
Para el proceso del montaje en la silla de ruedas del paciente, es necesario realizar la sujeción del dispositivo en el eje de la silla de ruedas, así como en una de las barras, a continuación, será necesario que se ajuste el largo de la palanca para que se adecue a la ergonomía del paciente, por último deberemos explicar el funcionamiento del dispositivo al paciente.
El dispositivo funcionara de la siguiente manera: al momento de colocar las correas en la mano el paciente tendrá que verificar si la palanca de cambio está en avance o retroceso, y lo tendrá que cambiar de acuerdo al movimiento que realizará a continuación tendrá que repetir el movimiento de palanca de hacia adelante , una vez quiera detenerse tendrá que poner la palanca modo inmovil y desacoplarse las correas

Diagrama de flujo “primer uso”: Requiere el apoyo de un externo que comprenda el funcionamiento del dispositivo y pueda realizar la parte manual.

Diagrama de flujo “uso cotidiano”: Es de uso completamente independiente del paciente.


Estaciones de trabajo
Espacio de uso para el producto:
El dispositivo está diseñado para utilizarse en una silla de ruedas estándar, permitiendo su uso tanto en entornos clínicos como domiciliarios.
Las pruebas iniciales se harán en la Universidad Peruana Cayetano Heredia (UPCH), en un entorno controlado para evaluar la funcionalidad del sistema. Posteriormente podrá ser probado en instituciones de rehabilitación, bajo supervisión fisioterapéutica.

Necesidades adicionales para pruebas de funcionalidad:
- Supervisión de un fisioterapeuta durante los ajustes iniciales.
- Un espacio de 5 a 10 metros de recorrido libre para pruebas de desplazamiento.
- Herramientas básicas (llaves Allen, destornilladores, pinzas) para ajustes menores.
- Correas ajustables para asegurar la mano del paciente a la palanca, evitando deslizamientos y mejorando la ergonomía durante el uso.

Automatización
Nivel de automatización:
El dispositivo presenta un nivel medio de automatización, ya que el sistema mecánico asiste al paciente mediante resortes de retorno y un mecanismo de ratchet que regula el sentido del giro y evita el retroceso de la rueda, mientras que la palanca amplifica el esfuerzo del usuario, facilitando la propulsión con menor fuerza aplicada.

Justificación técnica y clínica del nivel:
Desde el punto de vista técnico, el sistema es puramente mecánico, compuesto por engranajes, piezas de tope, resortes y una palanca que actúan de forma sincronizada dentro del mecanismo ratchet. El nivel medio de automatización se justifica porque el dispositivo reduce el esfuerzo físico del usuario al aprovechar la ventaja mecánica de la palanca y el sistema unidireccional del ratchet, que permite la propulsión hacia adelante con la mano firmemente sujeta mediante correas, evitando el riesgo de retroceso y manteniendo un control seguro y estable durante el movimiento.

Desde el punto de vista clínico, este nivel es adecuado para pacientes con lesión medular C3 completa, quienes conservan movilidad parcial de los brazos pero carecen de fuerza de agarre. El sistema posibilita una propulsión activa-asistida, fomentando la independencia funcional y reduciendo la fatiga muscular. Además, la sujeción de la mano mediante correas ajustables permite al usuario empujar la palanca sin necesidad de cerrar la mano, garantizando un contacto firme, seguro y ergonómico durante la propulsión.

Escenarios de seguridad:
- ¿Qué ocurre si el paciente pierde el control o suelta la palanca?
La palanca regresa automáticamente a su posición neutra mediante el resorte interno, deteniendo el avance de la rueda para evitar desplazamientos involuntarios.
- ¿Qué pasa si el ratchet “salta” o no acopla correctamente?
El movimiento de la palanca no se transmite a la rueda; se debe detener el uso, revisar el encaje del mecanismo y lubricar los componentes antes de continuar, para evitar daño por fricción o desgaste.
- ¿Qué sucede si los componentes se desgastan o fallan con el tiempo?
Las piezas críticas (engranajes, resortes y topes) son reemplazables individualmente y están hechas de acero.
- ¿Qué pasa si la palanca se mueve bruscamente o golpea una articulación?
El sistema cuenta con topes mecánicos que limitan el recorrido de la palanca, evitando la sobreextensión del codo o del hombro y reduciendo el riesgo de lesiones durante la propulsión.

Interfaces de red global
El sistema del dispositivo es puramente mecánico, y de uso cotidiano del paciente, independiente de la supervisión de un técnico, terapeuta o familiar. El dispositivo no cuenta con componentes eléctricos que requieran procesamiento y análisis de datos. Por lo tanto, no existen ni se requieren interfaces.

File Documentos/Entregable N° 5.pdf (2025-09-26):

Entregable N° 5: Ventajas y desventajas de los productos existentes

1. Identificación de la necesidad:
El caso clínico seleccionado corresponde a cuadriplejia grado A (completa) por daño en vértebra C3 tras un accidente de tránsito. Actualmente, el paciente Palacios puede desplazarse remando su silla de ruedas (con apoyo) gracias a la zona de preservación parcial (ZPP); sin embargo, es dependiente para el resto de actividades cotidianas. Debido a su condición, el paciente se encuentra inhabilitado de cumplir cualquier función laboral. Después de una breve entrevista, se identificó como prioritaria la necesidad de dispositivos de asistencia que le permitan recuperar autonomía, especialmente en tareas que requieren motricidad fina, como el aseo personal. El relato del Sr. Palacios evidenció el alto valor psicosocial que estas actividades tienen para su calidad de vida y autoestima. Esta necesidad coincide con la evidencia recabada en la búsqueda de patentes, la cual subraya la demanda de soluciones versátiles y altamente adaptables en este ámbito.
2. Búsqueda de patentes

PATENTE [1]:

Número de patente / Publicación: ES2804085T3
Título: Sistema de asistencia de movimiento para sillas de ruedas Inventores: RICHTER, MARK
Año de publicación: 2021
Entidad solicitante: MAX MOBILITY, LLC

Resumen funcional:
El sistema consta de una rueda motorizada accionable mediante un pulsador que se acopla a la estructura de la silla. Además, presenta dos ruedas delanteras que se mueven en dirección tangencial a la rueda posterior, para facilitar el movimiento curvo. Para desplazarse, el usuario debe únicamente accionar el botón del pulsador.

Aspectos innovadores:
Este sistema conserva parcialmente la actividad física del usuario, mientras que otros la reemplazan completamente. Además, no se requiere de sensores y mejora la movilidad gracias a las ruedas delanteras.

Limitaciones o vacíos:
El mecanismo podría limitar el movimiento en superficies irregulares, aunque poco comunes en entornos clínicos. Por otro lado, para el correcto funcionamiento se necesita implementar este mecanismo a un ángulo de 40° respecto de la horizontal, lo cual no es compatible con algunas sillas de ruedas.

Relación con la necesidad:
Esta patente brinda una solución a la dificultad del paciente para remar su silla de ruedas, brindando un soporte adicional y un impulso extra.

Imagen/es asociadas:


PATENTE [2]:

Número de patente / Publicación: WO2015047070A1
Título: Orthotic device for assisting with bending and extending movements of the fingers of a hand, for patients suffering from paralysis of the brachial plexus Inventores: Pol Torres Martinez, Rosa Flores Luna, Mariano Garcia Del Gallego, Jesús Dorador Gonzalez
Año de publicación: 2015
Entidad solicitante: Universidad Nacional Autónoma de México

Resumen funcional:
Patente de un sistema robótico para asistencia y rehabilitación del brazo y la mano, que integra un exoesqueleto ligero con sensores y actuadores controlados por señales fisiológicas y/o comandos externos. Está orientado a ayudar a pacientes con movilidad reducida o nula (ictus, lesión medular, etc.) a recuperar o mejorar el movimiento, y también a permitir teleasistencia y tele-rehabilitación.

Aspectos innovadores: (qué aporta o mejora).
- Control multimodal: puede usar señales neuromusculares (EMG), cinemáticas o control remoto para mover el exoesqueleto, adaptándose al grado de discapacidad del usuario.
- Combina varios grados de libertad del brazo y la muñeca con posibilidad de añadir asistencia a la mano.
- El sistema soporta parte del peso del brazo/objeto para que el usuario progresivamente pueda adaptarse.
- Su software permite programar restricciones, fuerzas o trayectorias para guiar la rehabilitación y medir el desempeño del paciente .

Limitaciones o vacíos: (qué problemas no resuelve).
- Su costo es elevado debido a su complejidad, ya que integra actuadores, sensores, comunicaciones y VR.
- El sistema debe ser fijado a estructuras y depende de alimentación externa, lo que lo vuelve poco portátil y no autónomo.
- La recuperación de movilidad que ofrece a la mano no es detallada e independiente de cada dedo, sino que trabaja en la mano como conjunto lo que limita el desenvolvimiento del paciente.

Relación con la necesidad:
La patente está orientada a recuperar movilidad funcional en las manos, favoreciendo así la independencia en actividades básicas de la vida diaria de personas con limitaciones de movimiento como es el caso de nuestro paciente. Aunque no ofrece control independiente de cada dedo, la asistencia en movimientos globales de apertura, cierre y muñeca facilita la manipulación de objetos y la realización de acciones sencillas.

Imágenes asociadas:


PATENTE 3:

Número de patente / Publicación: US20160015590A1 Título: Hand exoskeleton device
Inventores: Jumpei Arata, Roger Gassert
Año de publicación: 2014
Entidad solicitante: Universidad de Kyushu NUC

Resumen funcional:
Este invento busca una solución que ofrece un diseño compacto y ligero que lo hace montarse en la mano con comodidad, y genere suficiente fuerza para realizar movimientos de flexión y extensión. Usa un mecanismo de resorte deslizante para transmitir la fuerza de un actuador a las articulaciones de los dedos.

Aspectos innovadores:
1. Transmisión a múltiples articulaciones por un solo actuador, este invento propone un solo objeto que de el movimiento de la mano.
2. Estructura de tres capas de resortes con mecanismos deslizantes, incluye resortes superiores e inferiores conectados a piezas fijas, a su vez un resorte que acciona el movimiento.
3. Ajuste de sincronía de flexión mediante parámetros de resorte, usan las longitudes y rigidez del resorte para ajustar la activación de las articulaciones.
4. Minimización de mecanismos móviles y reducción de su peso
5. Adaptación anatómica
6. Aplicaciones a rehabilitación, ya que puede ser usado para entrenamiento de movimientos repetitivos.

Limitaciones o vacíos:
1. Capacidad de fuerza limitada por los resortes, estos deben usarse dentro del rango de deformación elástica para evitar malograr el dispositivo.
2. Complejidad mecánica, debido a complicaciones técnicas en el diseño este debe ser muy preciso sino afectará el rendimiento.
3. Falta de articulación independiente, ya que se usa un solo actuador, el control independiente de cada dedo es limitado.
4. No se aborda el pulgar en la implementación, no menciona una adaptación para el pulgar.
5. No se aborda cómo se alimenta el sistema o cuánta energía consume

Relación con la necesidad:
En relación al paciente, este exoesqueleto podría ayudar a generar movimientos de agarre, de esta manera incrementar la independencia para tareas finas, por otro lado podría realizarse una adaptación con señales residuales en el cual se usen sensores mioeléctricos para captar señales residuales en los músculos o señales nerviosas.

Imagen/es asociadas:


PATENTE [4]:

Número de patente / Publicación: AU2018364613A1 Título: Hand exoskeleton device (Bowden cables)
Inventores: Luca Randazzo y José del R. Millán
Año de publicación: 2019
Entidad solicitante: École Polytechnique Fédérale de Lausanne (EPFL, Suiza)

Resumen funcional:
El dispositivo es un exoesqueleto de mano modular y portátil que emplea cables que funcionan como un tendón para asistir los movimiento de los dedos (flexión/extensión). Está pensado para rehabilitación motora, así como para asistir en actividades diarias que requieren agarre, además no impide la sensibilidad táctil del usuario.

Aspectos innovadores:
- Diseño modular (se puede aplicar en 1 a 10 dedos).
- Motores / actuadores ubicados externamente (chest-pack) para reducir el peso en la mano (< 50g) y mejorar la comodidad.
- No cubre palma ni yemas, preservando la sensibilidad táctil.
- Uso de cables Bowden como “tendones artificiales”, lo que permite transmitir fuerza a distancia sin necesidad de mecanismos pesados en los dedos.

Limitaciones o vacíos:
- El chest-pack pesa ~ 930 g, lo que puede afectar al usuario (cansancio, incomodidad).
- La calibración y ajuste de los cables pueden ser complejos y requerir mantenimiento frecuente.
- No proporciona fuerza suficiente para manipular objetos pesados ni realizar tareas que demanden gran torque.
- No aborda movimientos complejos de la mano (como rotación de muñeca, oposición fuerte) .

Relación con la necesidad:
Este exoesqueleto mejora el agarre y la rehabilitación de la mano en pacientes con debilidad motora. En casos de lesión medular C3 completa, donde casi no existe movilidad funcional en brazos ni manos, brinda asistencia externa básica para recuperar funciones de agarre simple. Sin embargo, no resuelve tareas que demandan gran fuerza ni larga autonomía.


PATENTE 5:

Número de patente / Publicación: DOI: 10.1109/TMECH.2022.3148032
Título: FLEXotendon Glove-III: Voice-Controlled Soft Robotic Hand Exoskeleton With Novel Fabrication Method and Admittance Grasping Control
Inventores: Phillip Tran, Seokhwan Jeong, Fanzhe Lyu, Kinsey Herrin, Shovan Bhatia, Drew Elliott, Scott Kozin, Jaydev P. Desai
Año de publicación: 2022
Entidad solicitante: Georgia Institute of Technology en colaboración con Shriners Hospitals for Children

Resumen funcional:
Restaura la función de agarre en pacientes con lesión medular cervical mediante asistencia robótica activa de flexión y extensión de dedos. Permite realizar actividades de vida diaria como sostener objetos, beber, escribir y manipular elementos cotidianos a través de comandos de voz que activan diferentes patrones de agarre preprogramados.

Aspectos innovadores:
Fabricación personalizada con molde directo de la mano del usuario; sistema de tendones biomimético que replica la anatomía humana; control completamente por voz sin necesidad de interfaces físicas; control de admitancia adaptativo para diferentes rigideces de agarre; integración completa en smartphone con almacenamiento en nube; diseño portátil autónomo.

Limitaciones o vacíos:
Fuerza de pellizco limitada a 6.3 N; fabricación individual requerida; tendones expuestos en palma; control discreto con demoras; no maneja orientación de objetos; requiere estabilidad postural del brazo.

Relación con la necesidad:
El sistema está diseñado para lesiones C4-C5 donde existe control residual de hombro y codo. Para una lesión C3 con movimiento reducido de brazos podría ser parcialmente viable. Donde el control de voz jugaría un gran papel. El poco movimiento de los brazos podría permitir el posicionamiento básico para el agarre, aunque la precisión se vería afectada por el rango de movimiento reducido.

Imagen/es asociadas:


3. Reflexión Final:
La revisión de patentes muestra que, aunque existen múltiples dispositivos de asistencia para la movilidad de mano y brazo, ninguno resuelve completamente las necesidades de un paciente con cuadraplejia C3 completa. Esta condición implica una pérdida funcional casi total en brazos y manos, por lo que las soluciones deben ser más que un soporte mecánico: requieren ser ligeras, seguras, modulares y fáciles de usar con un diseño que favorezca a la comodidad del usuario. Además, la situación de estos pacientes demanda tecnologías que combinan bioseguridad, accesibilidad y portabilidad de modo que puedan ser usadas en diferentes entornos. Solo con un enfoque adaptado, integral y centrado en el usuario será posible generar un impacto real en su calidad de vida y su autonomía.

Bibliografía:
[1] M. Richter, “Sistema de asistencia de movimiento para sillas de ruedas”, ES2804085T3, 2021
[2] P. Torres, R.Flores, M. Garcia, J. Dorador “Orthotic device for assisting with bending and extending movements of the fingers of a hand, for patients suffering from paralysis of the brachial plexus”, WO2015047070A1, 2015.
[3] J. Arata, R. Gassert “Hand exoskeleton device” US20160015590A1, 2014
[4] J. Del R. Millán, L. Randazzo, “Hand exoskeleton device (modular, Bowden cable)”, AU2018364613A1, Ecole Polytechnique Fédérale de Lausanne, 2020.
[5] P. Tran, S. Jeong, F. Lyu, K. Herrin, S. Bhatia, D. Elliott, S. Kozin, and J. P. Desai, "FLEXotendon Glove-III: Voice-Controlled Soft Robotic Hand Exoskeleton With Novel Fabrication Method and Admittance Grasping Control," IEEE/ASME Trans.
Mechatronics, | vol. | 27, | no. | 5, | pp. | 3920–3931, | Oct. | 2022, | doi:
10.1109/TMECH.2022.3148032.

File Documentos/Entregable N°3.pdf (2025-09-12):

CASO [1]:

### 1. Caso de referencia

Edad: 46 años, sexo masculino
Diagnóstico: Fracturas múltiples de columna cervical C2-C6 secundarias a accidente automovilístico
- Fractura del cuerpo de C2 distal a apófisis odontoides
- Fracturas bilaterales de láminas de C3
- Fractura de lámina y pedículo de C4 con masa lateral flotante
- Fractura en lágrima del cuerpo vertebral de C5
Situación general: Trabajador que sufrió trauma raquimedular con compromiso neurológico.
Relevancia del perfil: Este caso es relevante porque representa fracturas cervicales múltiples (entidad relativamente infrecuente) con evolución neurológica favorable de ASIA C a ASIA D, permitiendo reintegración laboral completa.

### 2. Perfil funcional

Habilidades Conservadas:
Después de 19 meses:
- Reintegración laboral: Se reincorporó a sus actividades laborales tal como lo hacía previo a la lesión
- Movilidad cervical: Arcos de movilidad aceptables para el paciente
- Control de esfínteres: Normal.
- Clasificación neurológica: ASIA D

Limitaciones Principales:
- Déficit motor residual: Fuerza 4/5 en C6 y C7 del lado izquierdo únicamente *Escalas Clínicas Utilizadas:
ASIA (American Spinal Injury Association): Única escala mencionada en el artículo

### 3. Mapa de actividades críticas

Vida Diaria:
El artículo no especifica detalles sobre actividades de vida diaria específicas como vestirse, alimentarse, higiene personal, movilidad en casa ni transporte, pero debido a que la lesión que sufrió fue ASIA C y hubo una mejoría parcial, es probable que haya necesitado de ayuda al comer en todas estas actividades durante el periodo de rehabilitación,

Laborales:
Nivel de independencia: Independiente (reintegración completa)
Impacto en calidad de vida: Aparentemente mínimo, ya que logró una reintegración completa.

Rehabilitación:

No se hace mención de ninguna técnica de rehabilitación, solamente nos indica que el paciente fue enviado a rehabilitación y se hizo un seguimiento de él de forma externa.

Actividades Terapéuticas de Prevención/Progresión:
En el artículo no se especifica ninguna actividad terapéutica de prevención o progresión.

### 4. Barreras y facilitadores

Facilitadores:
El afectado tiene apoyo familiar ya que ellos lo trasladan, tiene acceso a un centro de atención a lesionados raquimedulares y tiene un seguimiento continuo en la consulta externa.

Barreras:
En el artículo no se mencionan cosas como el tipo de viviendo, el acceso a transporte, situación económica como para poder encontrar alguna barrera.

### 5. Mapa de dolor (Pain Point)

Durante tratamiento inicial:
El afectado al cuarto día de colocación de la esquelética con tenaza de Gardner, presentó deterioro neurológico progresivo en la fuerza y sensibilidad de las cuatro extremidades.

### 6. Expectativas del usuario (simuladas o tomadas de la literatura)

En el artículo no se menciona ninguna expectativa específica del paciente, ni tampoco ningún objetivo de corto o largo alcance. Pero al final del artículo se menciona que el paciente logró reintegrarse a sus actividades laborales, tal y como lo hacía antes de sufrir la lesión y lo único que se encuentra es un déficit en el motor parcial en C6 y C7 con fuerza ⅘ y por lo demás no presenta ninguna complicación. Así que se podría decir que un objetivo inicial era reintegrarse a las actividades laborales, lo cual ya se cumplió, y ahora un nuevo objetivo sería la completa recuperación de C6 y C7.

CASO [2]:

### 1. Caso de referencia

Edad: 46 años
Diagnóstico: fractura en columna cervical subaxial de transición, C7
Estado actual: funcionalidad preservada, independiente para actividades físicas y productivas.

Este perfil es relevante ya que nos ofrece un marco clínico estructurado para analizar sus capacidades conservadas, limitaciones físicas y psicosociales, además de las actividades terapéuticas realizadas en cualquier paciente que presente lesión medular.

### 2. Perfil funcional

Habilidades conservadas:
- Funciones sensoriales y auditivas: Escala Glasgow -> 14, lo que indica que está consciente, orientado y con adecuada respuesta.
- Autonomía parcial en AVD
- Funciones cardiorrespiratorias
Limitaciones:
- Movilidad: diagnostico NANDA(00085) lo cual presenta un deterioro de movilidad física, ya que es paraplejico de miembros inferiores
- Dolor: Fractura de cadera con EVA 8/10(dolor intenso en caderas) limitando movimientos
- Trastornos: diagnóstico NANDA(00095) lo que se relaciona a insomnio , diagnóstico NANDA(00146) lo que se relaciona andiedad y concentración disminuida
- Sobrepeso: Presenta IMC 26, con malos hábitos alimenticios
- Termorregulación: fiebre frecuente con diagnostico NANDA (00008) pues tiene termorregulación ineficaz

### 3. Mapa de actividades críticas

Vida diaria:
- Alimentación, higiene bucal y comunicación: es independiente aunque con movilidad reducida para ir al baño o cocina, requiere asistencia parcial
- Baño, vestirse y uso del retrete: dependiente, debido a paraplejia y dolores en la cadera, afecta su privacidad y autoestima

Laborales/educativas:
- Trabajo: no se menciona, sin embargo es independiente con algunas complicaciones como la movilidad, insomnio y estrés producido, ello le puede generar exclusión social y pérdida del empleo

Rehabilitación / fisioterapia:

Requiere ayuda parcial, presenta dificultades debido al dolor presente, falta de fuerza y sobrepeso, su recuperación actual es lenta y requiere de ayuda profesional

Actividades terapéuticas de prevención/progresión:
- Técnicas de relajación, higiene del sueño y educación alimentaria: independiente, pero con un supervisor, presenta ansiedad y resistencia al cambio de dieta, esto le está ayudando a mejorar su calidad de vida
- Control de peso, prevención de úlceras a presión y ejercicios respiratorios, requiere ayuda parcial, es complicado debido a su sedentarismo y hábitos alimenticios inadecuados, estas actividades tienen un impacto directo en su recuperación y mejorar el pronóstico.

### 4. Barreras y facilitadores

Barreras:
- Se menciona que el paciente sufre de estrés e irritabilidad debido a su espacio laboral, lo que empeora su estado psicológico, y crea una mayor dificultad en su reinserción a su vida social.
- No se comenta sobre adaptaciones en su espacio cotidiano, como rampas o barandillas lo que puede disminuir su movilidad independiente.
- Se omiten detalles sobre sus relaciones familiares, de las cuales pueda recibir apoyo.

Facilitadores:
- El paciente no presenta dificultades para acceder a servicios de salud que puedan mejorar su estado, como rehabilitación o fisioterapia.
- Presenta un plan médico detallado y adaptado para su caso y necesidades
- Actualmente vive en una zona urbana lo que facilita su transporte a los centros médicos u otros lugares que frecuenta.

### 5. Mapa de dolor (Pain Points)

Durante su trayecto al centro médico, el paciente presenta dolor intenso e impotencia funcional en extremidades inferiores, sobre todo en la zona izquierda de la cadera. El paciente verbaliza: “tengo malestar y dolor en miembros inferiores, pero no lo puedo sentir ni mover”. En la escala EVA su dolor se registró en 8/10.
Para su plan de cuidados, se modificaron las medidas de control en función de las respuestas del paciente. Además, se suministraron analgesicos las 24 horas del día durante las primeras 48 horas después del traumatismo.

### 6. Expectativas del usuario (simuladas o tomadas de la literatura)

En el caso clínico no se registran expectativas explícitas del paciente sobre su recuperación. Sin embargo, pacientes en condiciones similares suelen tener como expectativas principales, recuperar en lo posible la independencia en la cotidianidad, mantener el dolor bajo control y la reintegración a la sociedad. En el caso concreto del paciente, debido a su sobrepeso, es esperable que mejore sus hábitos alimenticios y realiza actividad física en la medida de los posible, de esta manera se pueden evitar complicaciones derivadas de la inmovilidad y mantener la calidad de vida, con respecto a su capacidad respiratorio y cardiovascular. Por último se esperaría que el paciente logre controlar sus niveles de ansiedad y de esta forma mejore su calidad de sueño y por ende su bienestar general.

CASO [3]:

### 1. Caso de referencia:

Paciente masculino de 26 años procedente de Iquitos fue admitido de emergencia al hospital de la ciudad luego de perder la conciencia tras un golpe en la región posterior del cuello. Luego de ser tratado con analgésicos, es dado de alta sin poder movilizarse. Dos días después, es llevado de emergencia al Hospital de Loreto por persistencia de síntomas, donde se le realizaron exámenes auxiliares y se le diagnosticó espondilolistesis grado II de C6-C7.

### 2. Perfil funcional

El paciente ha conservado el lenguaje, la orientación, la atención, la memoria y sus funciones cognitivas superiores. Sin embargo, ha perdido la función motora casi en su totalidad. Esto se evidencia en el resultado negativo de las pruebas de marcha y postura, fuerza múscular y tono múscular. Además, el reporte indica respuesta parcial de reflejos y descoordinación de miembros inferiores. El documento no indica las evaluaciones que se realizaron. Por otro lado, el paciente conserva el sueño conserva orina y deposiciones normales. Se reporta un elevado apetito y sed. Finalmente, se reporta alto nivel de conciencia (puntaje 14 en escala de Glasgow), por lo que el origen de la inmovilidad es la cuadriplejia desarrollada tras el daño en la médula.

### 3. Mapa de actividades

Vida diaria:
El paciente presenta una dependencia grado IV (dependencia total), requiriendo asistencia para todas las actividades de la vida diaria, incluyendo la alimentación, la higiene y el vestido. Debido a su condición, se mantiene en reposo absoluto.
En cuanto a su estado metabólico, presenta hiperfagia (apetito patológicamente aumentado) y polidipsia (sed excesiva). Se han conservado las funciones excretoras (micción y deposición normales) y el ciclo del sueño.

Laborales/educativas:
Se mantiene en reposo absoluto y presenta ansiedad por los grandes cambios como la consideración social.

### 4. Tratamiento médico

Manejo del Dolor e Inflamación:
- Reposo absoluto: Indicado para favorecer la estabilidad vertebral y la recuperación.
- Analgesia y antiinflamación: Se administrará pauta analgésica escalonada según la valoración del dolor (Intensidad del dolor del 1 - 10 ). El protocolo incluye metamizol y dexametasona.
- Sedación: Se maneja sedación suave para garantizar el descanso del paciente y facilitar el sueño.

Prevención de Complicaciones:
- Uso de colchón neumático antiescaras para redistribuir la presión y minimizar el riesgo de lesiones cutáneas.
- Vigilancia cutánea: Se realizan controles periódicos de la piel (especialmente en zonas de apoyo y prominencias óseas) para preservar su integridad.
- Apoyo psicológico y espiritual: Para fortalecer la resiliencia, la confianza, el autocontrol, el equilibrio emocional y la autoestima del paciente.

Medidas de Higiene y Confort:
- Baño y aseo general en cama: Realizado diariamente para mantener la higiene, prevenir infecciones y proporcionar confort.

Monitorización y Pruebas periódicas:
- Control de Constantes Vitales (CFV): Monitorización de constantes (frecuencia cardíaca, respiratoria, tensión arterial y temperatura) cada 6 horas.
- Hemograma completo: Para controlar el estado general y detectar posibles signos de infección o anemia.
- Tomografía Axial Computarizada (TAC o TEM) de columna cervical: Para evaluación y seguimiento de la patología vertebral.
- Antibioterapia: El objetivo es prevenir la progresión de una infección existente o evitar una infección secundaria.

### 5. Barreras y facilitadores

Posterior a su lesión medular, el paciente se desempeñaba como operario en una distribuidora, trabajo que se vería impedido de realizar tras el desarrollo de la cuadriplejia. El grado de instrucción (secundaria completa), podría representar una barrera en la reinserción en el mundo laboral. Por otro lado, el Hospital de Loreto podría presentar deficiencias en infraestructura necesaria para una correcta y eficiente rehabilitación.
Sin embargo, el paciente conserva sus funciones cognitivas y procesos mentales elementales, así como un ligero control de las extremidades superiores que puede ser tratado con rehabilitación.

### 6. Mapa de dolor (Pain Points)

- El paciente tiene dolor agudo debido a la lesión traumática. Requiere analgésicos y sedación para disminuir el dolor de un 8 a un 5.
- Siente ansiedad constante relacionados con los cambios abruptos generados por la lesión y constantemente se siente preocupado por su estatus económico actual, estado de salud y rol en la sociedad y en la familia.

### 7. Expectativas del usuario (simuladas o tomadas de la literatura)

Se espera que los pacientes cuadripléjicos puedan recobrar una gran parte de su autonomía, mediante rehabilitación e implementación de dispositivos de ayuda propia [4]. Para el paciente del reporte, se espera recuperar la movilidad parcial en miembros superiores.

Bibliografía:

[1] Vargas-Mena, R., Dufoo-Olvera, M., García-López, O., López-Palacios, J., Aburto-Trejo, J., & Capiz-Ruiz, E. (n.d.). Fracturas múltiples de la columna cervical: Reporte de un caso.
https://www.scielo.org.mx/scielo.php?script=sci_arttext&pid=S2306-41022014000500 009 (https://www.scielo.org.mx/scielo.php?script=sci_arttext&pid=S2306-41022014000500009)
[2] C. Calderón Céspedes, Y. Huamani Maruri, L. Sánchez Mauricio, K. Segura Hidalgo, and
S. H. Gonzales Saldaña, “Cuidado enfermero en paciente adulto con traumatismo de médula espinal y sobrepeso,” Investigación e Innovación, vol. 2, no. 2, pp. 111–124, 2022, doi: 10.33326/27905543.2022.2.1500.
[3] Ilide. (s. f.). Caso clínico de TVM cervical (C6–C7) [PDF].
[4] Orejuela-Zapata, C. A. (2019). Dispositivos de ayuda para personas con cuadriplejia: Revisión de la literatura https://doi.org/10.1109/TNSRE.2019.2901399

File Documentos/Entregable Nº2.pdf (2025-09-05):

### 1. Análisis del caso:

a. Información personal:
Nombre | No mencionado
Procedencia | Natural y procedente de Lima
Edad | 28 años
Género | Masculino

Médicos

Fuente y motivo de referencia | Proveniente de una clínica local, el paciente acudió al INR
Tratamiento médico/terapéutico y sus objetivos | Tratamiento farmacológico para control de dolor y funcion urinaria en vistas de recuperar la autonomía del paciente
b. Financiamiento:

Se presume que su tratamiento es de financiamiento personal. El paciente no fue derivado de ningún hospital ni centro clínico; acudió por sus propios medios al INR. Se desconocen los datos sobre la aseguradora y número de póliza. Una fuente adicional de financiamiento consiste en la evaluación del Departamento de Ayuda en el Tratamiento al paciente para determinar su inclusión en el programa. Este incluye acceso a servicios de farmacia, nutrición, ortodoncia y rehabilitación profesional.

c. Diagnósticos e historial médico:

En primera instancia, el paciente fue diagnosticado con fractura vertebral C6 y C7 luego de haber sufrido un fuerte traumatismo craneal. Para esto, se le practicó una laminectomía de C7 + fijación anterior y artrodesis cervical anterior. Luego de su tratamiento en el INR, el diagnóstico cambió a traumatismo de médula espinal NN C7, AIS “B” por zambullida. Debido a los procedimientos a los que se ha sometido, el paciente está impedido de utilizar tecnología que involucre movimientos forzosos del cuello, cómo máquinas de tracción cervical, gafas de realidad virtual muy pesadas o dispositivos que estimulen a altas frecuencias la zona cervical. No se ha planeado ninguna intervención quirúrgica futura; se focaliza el proceso en recuperar la autonomía y la reinserción social y profesional.

Actualmente, el paciente sigue un tratamiento con diversos medicamentos. Gabapentina, Carbamazepina, Baclofeno y Diazepam para la relajación muscular y control de dolores cervicales, Tamsulosina y Nitrofurantoína para estimular la función urinaria y Omeprazol para controlar los efectos gástricos producidos por la Nitrofurantoína.

El paciente ha conservado la deglución y posee un lenguaje oral adecuado. En cuanto a las funciones respiratorias, no se evidencia ningún daño significativo en los pulmones y existe una ventilacioń espontánea en ambos campos sin ruidos agregados. El corazón no presenta latidos irregulares y no se escuchan soplos. Además, tampoco existe evidencia de trombosis vascular.

d. ‘Estado psicosocial:

El paciente ha conservado su cognición y mantiene una comunicación normal; sin embargo, se evidencian alteraciones en sus interacciones sociales a tratar en terapias de reinserción social. Además su conducta no se ha visto modificada radicalmente y su ánimo es normal. Pese a la falta de detalles internos, se desprende una correcta relación con su familia quienes lo apoyan en los procedimientos necesarios, como el cateterismo. Se presume que el pacientes podría estar familiarizado con el uso de tecnología dada su formación en Actualmente se encuentra desempleado.

Por otro lado, el paciente depende de ayuda en todas sus actividades cotidianas. En busca de mejorar su estado psicosocial, se busca que el paciente pueda desplazarse independientemente en silla de ruedas e incluirlo en un programa para la rehabilitación profesional.

e. Estado neuromuscular y musculoesquelético:

El paciente presenta interrupción del sueño debido a dolor constante en el antebrazo derecho con irradiación hacia la mano derecha, así como en la muñeca izquierda con irradiación hacia la mano. El dolor es predominantemente nocturno y de carácter lancinante. Se evidencia tono muscular aumentado en los miembros superiores (Ashworth = 3, Penn = 3).

Hallazgos positivos:

1. Dolor lancinante nocturno en antebrazo derecho y muñeca izquierda con irradiación a manos.
2. Aumento del tono muscular en miembros superiores (Ashworth = 3, Penn = 3).
3. Babinski (+) bilateral.
4. Clonus (+) bilateral.
5. Reflejos sacros: perianal positivo, bulbocavernoso positivo.
6. Tono de esfínter (+++).
7. Reflejo de laos (+).
8. Coordinación conservada en presencia de movimiento voluntario.

Hallazgos negativos:
1. Contracción voluntaria de esfínter anal externo (-).
2. Beecor (-).

Examen de fuerza muscular de miembros superiores(derecha/izquierda):
1. Flexores de codo: 5/5
2. Dorsiflexores de muñeca: 5/ 5
3. Extensores de codo: 3/3
4. Abducción de 5° dedo: 0/ 1 El resto está ausente.

Examen de fuerza muscular de miembros superiores(derecha/izquierda):
1. Flexores de cadera: ausente
2. Extensores de rodilla: ausente
3. Dorsiflexores: ausente
4. Extensores de primer dedo: ausente
5. Plantiflexores: ausente
f. Afección de la piel:

No se encontró ninguna alteración, sino un color rosado en piel y mucosa, lo que indica buena oxigenación. Sin embargo, por su condición de postrado, y con el objetivo de evitar que desarrolle úlceras por presión, se recomienda realizar acciones preventivas tales como cambiar de posición de forma constante (cada 3 horas), uso de almohadas en silla y cama, entre otros [1]. Por otro lado, el uso del pañal puede generar dermatitis, por lo que se requiere mantener la zona perineal y perianal, limpia y libre de humedad [2].

g. Función sensorial:

El afectado presenta sensibilidad superficial en brazos y manos, presenta sensibilidad en la zona anal y perianal. En cuanto a los reflejos resultaron Babinski (+) bilateral lo que quiere decir que hay una lesión en vías motoras de la médula o cerebro, Clonus (+) bilateral lo que indica sacudidas repetitivas al estirar un músculo, Reflejos sacros Perianal (+) y Bulbocavernoso (+) lo que quiere decir que los reflejos alrededor del ano funcionan correctamente, Tono del esfínter (+++) esto indica que el ano está cerrado con fuerza y Reflejo de latos (+).

h. Habla, lenguaje, comunicación:

El afectado puede comunicarse sin problemas.

i. Desempeño funcional, de habilidades y de tareas:

El afectado es dependiente en todas las actividades de la vida diaria.

j. Movilidad personal:

El afectado necesita de 2 personas y una tabla de traslación, pero no logra sedestación

k. Transporte comunitario:

El paciente depende principalmente del apoyo familiar para trasladarse en automóvil particular o taxi, ya que no utiliza transporte público debido a la falta de accesibilidad y a su alta dependencia física. La entrada y salida del vehículo requiere la asistencia de al menos dos personas, pues no cuenta con rampas ni sistemas de elevación, y la transferencia se realiza con tabla y ayuda física. La silla de ruedas debe ser plegada y cargada manualmente en el maletero del vehículo, lo que representa una dificultad logística adicional. En la práctica, el transporte comunitario del paciente se encuentra restringido a distancias cortas y a desplazamientos específicos para consultas médicas y terapias.

l. Entornos:

El paciente vive en Lima en un hogar que no cuenta con adaptaciones arquitectónicas ni baño accesible, lo que incrementa su dependencia familiar para las actividades básicas. Su participación comunitaria es limitada y se restringe a consultas médicas y sesiones de rehabilitación, ya que se encuentra desempleado y sin actividades recreativas. Aunque el entorno físico del hogar presenta condiciones adecuadas de luz, ventilación y temperatura, las principales limitaciones se centran en la accesibilidad y en la falta de infraestructura adaptada. En el aspecto psicosocial, mantiene un buen vínculo con su familia, que constituye su principal red de apoyo, aunque la pérdida de empleo y la dependencia funcional reducen su integración social y vocacional. El entorno es compatible con la incorporación de tecnologías de asistencia, siempre que se implementen adaptaciones básicas como rampas o barras de apoyo que favorezcan la independencia y la reinserción del paciente.

m. Historial de equipos anteriores:
El paciente no refiere el uso de equipos tecnológicos previos a su accidente, pues llevaba una vida independiente. Tras la lesión medular comenzó a utilizar una sonda vesical permanente, posteriormente reemplazada por cateterismo intermitente. Además, se emplearon pañales y papagayo nocturno como apoyo para la continencia urinaria y fecal.
n. Equipo actual:
Al momento de su evaluación en el INR (mayo de 2024), el paciente utilizaba una silla de ruedas a medida con cojín de asiento adaptado como principal medio de movilidad. Su uso era asistido por terceros, ya que no lograba autopropulsarse de manera independiente. Asimismo, empleaba catéteres intermitentes, pañales y papagayo nocturno como apoyos para el manejo de la continencia urinaria y fecal. Dicho equipo le permitía cubrir necesidades básicas de movilidad y cuidado, aunque limitaba de manera significativa su independencia funcional.

### 2. Resumen de paciente:

a) Usuario/Paciente: Describe las habilidades y capacidades de la persona con discapacidad(caso asignado).

Lenguaje y comunicación: puede hablar y expresarse normalmente.
Deglución: no tiene problemas para alimentarse por boca.
Nervios craneales: no se presenta una alteración en los pares craneales, por lo cual puede ver, escuchar, mover los músculos de la cara, y la lengua funcionan sin problemas.
Movilidad activa: disminuida en los miembros superiores y ausente en miembros inferiores, por ello necesita ayuda de 2 personas para trasladarse
Movilidad pasiva: un rango limitado de funciones
Sensibilidad:

- Conserva la sensibilidad superficial hasta brazos y manos.
- Conserva la sensibilidad en la zona anal y perineal.
- Tiene sensibilidad anal profunda.

Coordinación: donde logra mover voluntariamente, como los brazos, lo hace con coordinación adecuada.
Reflejos sacros: perianal y bulbocavernoso presentes.
Respiración: respira por sí mismo, los pulmones funcionan bien.
Micción: presenta incontinencia por lo que se hace uso de catéter. Deposiciones: presenta complicaciones y usa un pañal.
b) Actividad: Describe el conjunto de tareas a realizar por la persona con discapacidad (caso asignado).
- Rehabilitación física y funcional
- Realizar actividades de rehabilitación en miembros superiores para conservar su movilidad
- Estiramiento para prevenir rigidez
- Cuidados posturas y cambio de posición para prevenir úlceras por presión
- Seguir indicaciones fisicoterapeuticas sobre el tono muscular y dolores
- Autonomía personal y actividades de vida diaria
- Aprender a controlar la silla de ruedas debe manera independiente
- Entrenar para usar apoyos de transferencia para pasar a su cama u otros.
- Organizar rutina de evacuación intestinal y cuidadores de piel
- Desarrollar habilidades para alimentarse de manera autónoma
- Adaptaciones psicosocial y personal
- Evaluación psicológica para adaptarse a la vida con discapacidad
- Explorar opciones de reinserción laboral adaptada a su discapacidad
- Entrenarse junto a su familia en técnicas de cuidado y asistencia
c) Contexto: Describe el entorno o contexto social, cultural y físico que rodea el entorno en el que debe realizarse la actividad.
- Contexto social
- Familiar: vive con familiares o cuidadores qué lo apoyan en sus actividades diarias
- Comunitario: al ser joven, profesional y con amistades, presenta redes de apoyo y posibilidades para encontrar empleo
- Contexto cultural
- Formación y ocupacion: presenta formación profesional completa. Lo que le permitirá conseguir un empleo adaptado y desarrollar nuevas habilidades
- Actitud social: aunque en la sociedad actual en Lima llega a ser discriminado, hay leyes, políticas y programas para apoyar a personas con discapacidad
- Contexto físico:

- Vivienda: No cuenta con espacios adaptados a sus necesidades, como el baño.
- Movilidad: Requiere de silla de ruedas, por lo que necesita de espacios amplios para movilizarse por su hogar y calles.
- Centro de salud: Acude al Instituto Nacional de Rehabilitación, el cual cuenta con los profesionales adecuados
- Espacio urbano: En Lima se pueden presentar dificultades para transitar por las calles.
d) Tecnología: dispositivos o estrategias utilizadas para cerrar la brecha entre las capacidades de la persona y las demandas del entorno

Actualmente hace uso de una silla de ruedas a medida asistida por un tercero para su movilidad, su vivienda no presenta adaptaciones que faciliten su independencia, y requiere a un familiar para la gran mayoría de actividades. Se requiere la implementación de tecnologías y adaptación a las mismas, para que pueda recuperar cierta independencia.

- Silla de ruedas mecánica simple para su locomoción
- Adecuación de herramientas como utensilios de comida.
- Acondicionamiento del entorno por medio de rampas, ampliación de puertas, etc.

Bibliografía:
[1] Z. De Figueiredo, J. Tirado, F. Mulet, A. Nuñez, L. De Andrade, M. Di Ciero, M. Soares. “Úlceras por presión en personas con lesión medular: conocimiento de familiares y cuidadores.” av.enferm. vol.28, 2010.
[2] A. Benitez, M. Mendez. “Dermatitis de pañal”, StarPearls, 2023

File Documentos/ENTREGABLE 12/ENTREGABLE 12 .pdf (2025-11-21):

ENTREGABLE N° 12: SECCION DEL PLAN
1. Contexto de uso

El dispositivo está dirigido al paciente Palacios, quien busca recuperar mayor autonomía en su movilidad diaria. Su uso principal será en el Instituto Nacional de Rehabilitación, donde realiza sus terapias y controles, aunque también se planea que funcione en espacios domésticos adaptados, como su casa, pasillos internos o patios con piso estable. La silla de ruedas con palanca regulable está diseñada para aprovechar el movimiento residual que conserva en brazos y hombros, permitiéndole desplazarse con menos esfuerzo y sin depender constantemente de un acompañante. Se espera que el uso sea frecuente y por periodos prolongados, tanto durante la rehabilitación como en actividades cotidianas. Un cuidador o terapeuta podría brindar apoyo inicial en la colocación o ajuste del equipo, pero el objetivo principal es que el paciente pueda accionar la palanca por sí mismo y manejar su desplazamiento, fomentando así su independencia.
2. Perfil de usuario
El paciente Palacios presenta una lesión medular a nivel C3 producto de un accidente de tránsito, que resultó en una cuadriplejia completa (grado A). Aun así, conserva algo de movilidad en brazos y hombros gracias a una zona de preservación parcial (ZPP), lo que le permite generar movimientos de empuje. No posee control del tronco ni de las extremidades inferiores, por lo que requiere asistencia de cuidadores para la mayoría de sus actividades diarias. En el aspecto cognitivo se encuentra totalmente alerta y orientado. Durante la entrevista, mostró motivación y un fuerte deseo de recuperar cierto nivel de autonomía, especialmente en tareas que le brinden sensación de control sobre su entorno. Poder desplazarse por cuenta propia no solo implicaría un avance funcional, sino también un logro personal con impacto positivo en su autoestima y bienestar emocional.
3. Análisis de tareas
Tarea | Descripción | Tipo | ¿Crítica ? | Justificación
Posicionar la silla de ruedas | Colocar la silla en un área adecuado antes del montaje inicial | Primer uso | No | Se realiza sin el paciente sentado, por lo que no implica riesgo.
Sujetar el dispositivo al eje de las ruedas | Instalar el sistema ratchet en el eje y fijarlo a la estructura de la silla | Primer uso | Sí | Un montaje incorrecto puede bloquear el movimiento, desgastar piezas o soltarse.
Ajustar largo de palanca | Modificar la longitud de la palanca según la postura del usuario | Primer uso | No | Solo influye en la ergonomía, no en la seguridad inmediata.
Colocar correas de | Ajustar las correas alrededor de la mano | Primer uso y uso diario | Sí | Si se sueltan, el usuario podría perder el control

sujeción | del paciente | | | del movimiento.
Capacitación para su uso | Aprender cómo funciona el selector (adelante/atrás/inmó vil) | Primer uso | No | Necesario, pero puede reforzarse fácilmente con la práctica supervisada.
Verificar posición del selector | Revisar visualmente que la dirección elegida sea la correcta antes de impulsar | Uso cotidiano | Sí | Seleccionar una dirección incorrecta puede causar movimientos imprevistos o choques.
Cambiar selector a la dirección deseada | Ajustar el selector según el tipo de desplazamiento que se va a realizar | Uso cotidiano | Sí | Un cambio equivocado puede provocar que la silla avance en sentido contrario.
Ejecutar movimiento de palanca | Hacer los empujes que generan el avance de la silla | Uso cotidiano | No | Es la función principal y está limitada por topes que previenen movimientos peligrosos.
Cambiar a modo inmóvil para detenerse | Activar el freno antes de soltar la palanca y las correas | Uso cotidiano | Sí | Garantiza que la silla no continúe moviéndose sin control.
Desacoplar correas | Retirar las correas de las manos una vez finalizado el uso | Uso cotidiano | No | Es seguro siempre que la silla esté previamente fijada en modo inmóvil.
Revisar estado de resortes | Evaluar periódicamente si los resortes devuelven la palanca a su posición | Mantenimiento | Sí | Resortes deteriorados afectan el retorno y pueden comprometer la operación segura.
Verificar y lubricar mecanismo ratchet | Revisar que encaje correctamente y aplicar lubricación preventiva | Mantenimiento | Sí | La falta de lubricación puede producir fallas en el acople o en la transmisión del movimiento.
Inspeccionar engranajes y piezas de tope | Revisar el desgaste de los componentes metálicos del sistema | Mantenimiento | Sí | El deterioro puede disminuir el acoplamiento y generar fallos mecánicos.

4. Criterios de éxito
Para validar la usabilidad y funcionamiento de nuestro sistema de tracción asistida para un paciente con lesión medular a nivel C3, definimos criterios que permitirán verificar si el dispositivo cumple con los requisitos mínimos de eficacia, seguridad y facilidad de uso.
Criterio | Característica / Métrica Objetiva
Eficacia | El usuario debe activar el modo de tracción en menos de 2 intentos y avanzar sin apoyo externo.
Eficiencia | El cambio de modo mediante el switch debe hacerse en menos de 1 minuto.
Satisfacción del usuario | El usuario debe manifestar comodidad y comprensión del sistema, obteniendo una puntuación ≥ 4/5 en una escala de facilidad y confort.
Seguridad | El mecanismo no debe trabarse (0 fallas), no debe provocar lesiones y debe soportar adecuadamente las cargas de uso.
Comprensibilidad | El usuario debe identificar correctamente el modo TRACCIÓN/LIBRE usando el LED, alcanzando al menos un 90% de aciertos.
Esfuerzo físico | La fuerza necesaria para accionar la palanca no debe exceder ~20 N, alineándose con la capacidad muscular de un paciente con lesión C3. [1]


Fotos:

REFERENCIAS:
[1] H. Hoffman, T. Sierro, T. Niu, M. E. Sarino, M. Sarrafzadeh, D. McArthur, V. R. Edgerton, and D. C. Lu, “Rehabilitation of hand function after spinal cord injury using a novel handgrip device: a pilot study,” Journal of NeuroEngineering and Rehabilitation, vol. 14, no. 1, Art. no. 22, Mar. 2017, doi: 10.1186/s12984-017-0234-1.

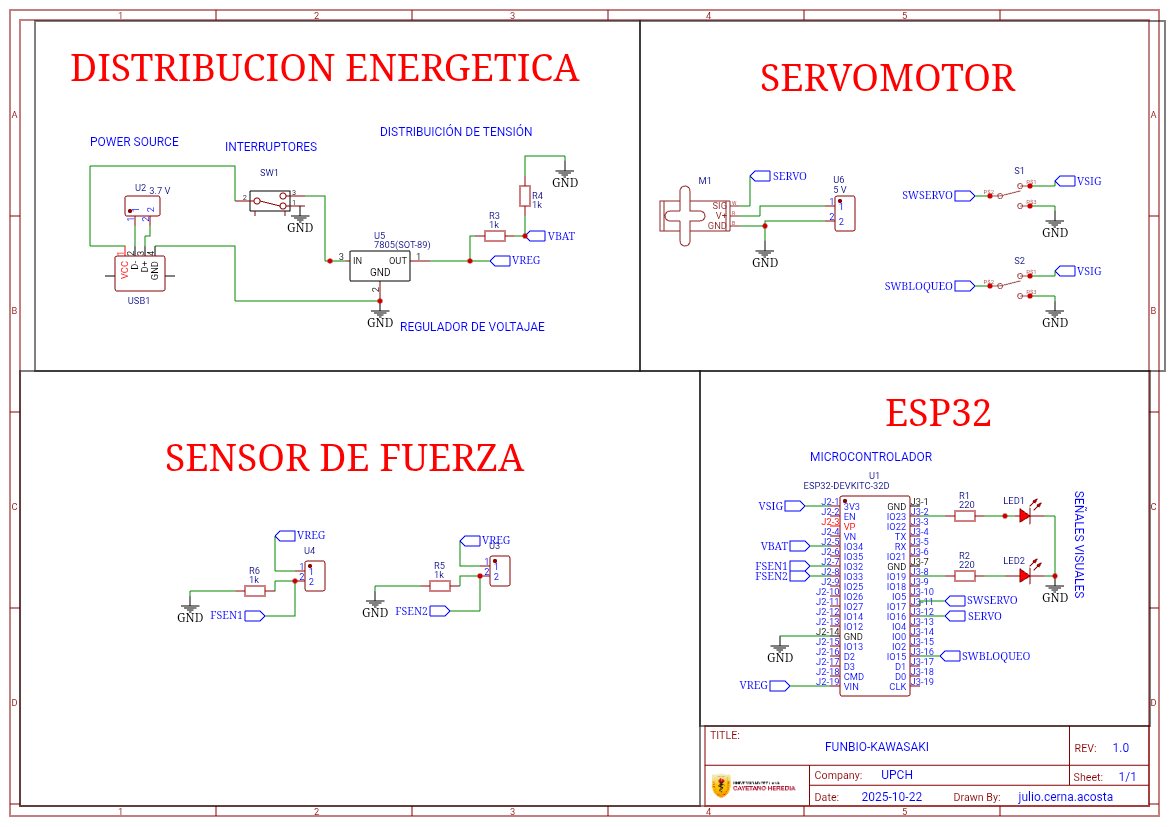
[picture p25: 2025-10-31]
Documentos/Entregable N°9/Electrónica/Schematic_FUNBIO23-copy-copy_2025-10-30.png

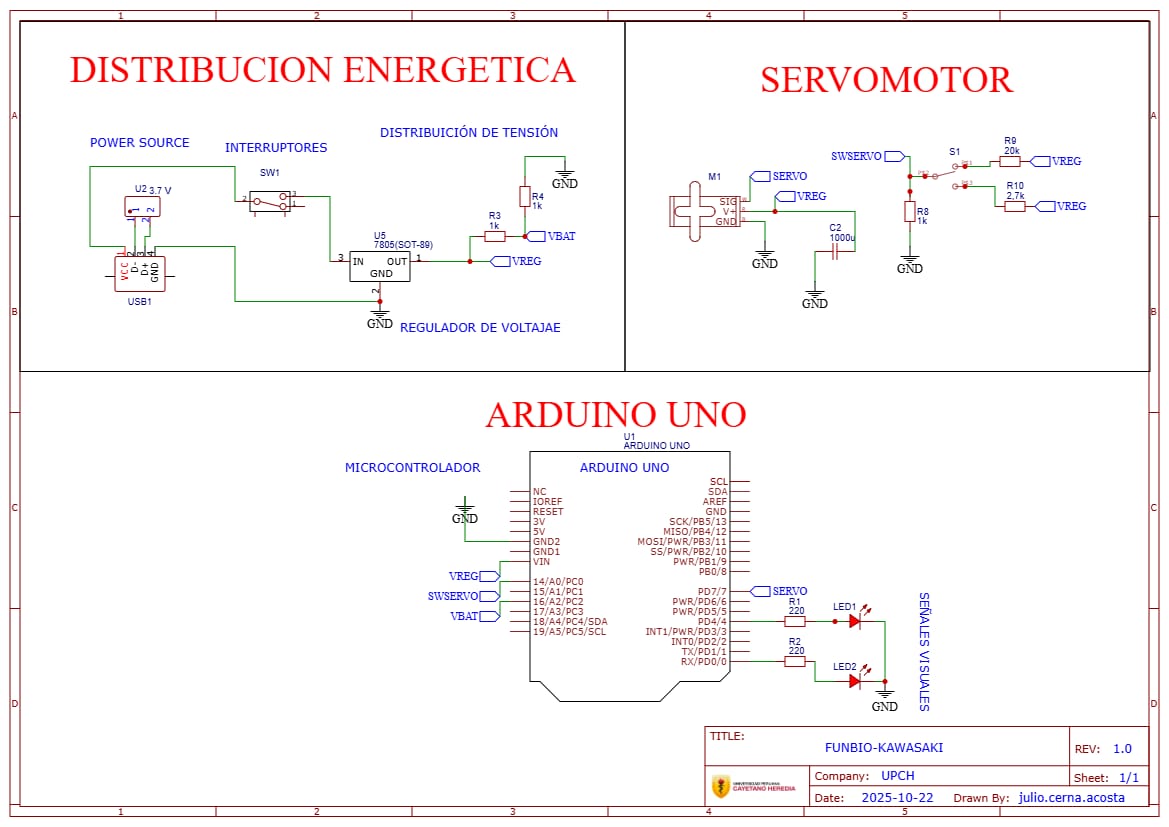
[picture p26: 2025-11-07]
Documentos/Entregable N°10/Prototipado electrónico/Esquema.jpg

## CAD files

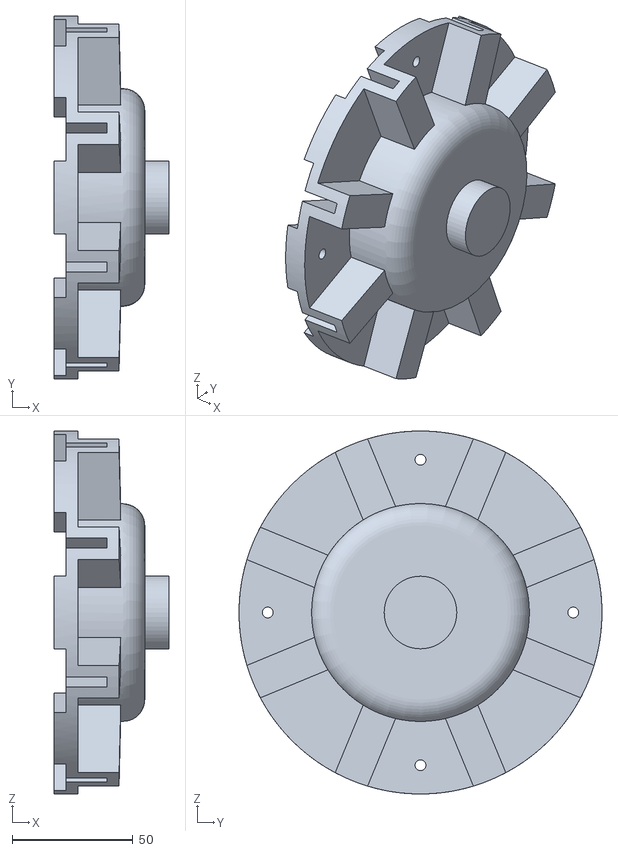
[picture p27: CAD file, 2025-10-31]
Documentos/Entregable N°9/Piezas stl/A_Tapa _grosor _5mm.stl
47.5 x 150.0 x 150.0

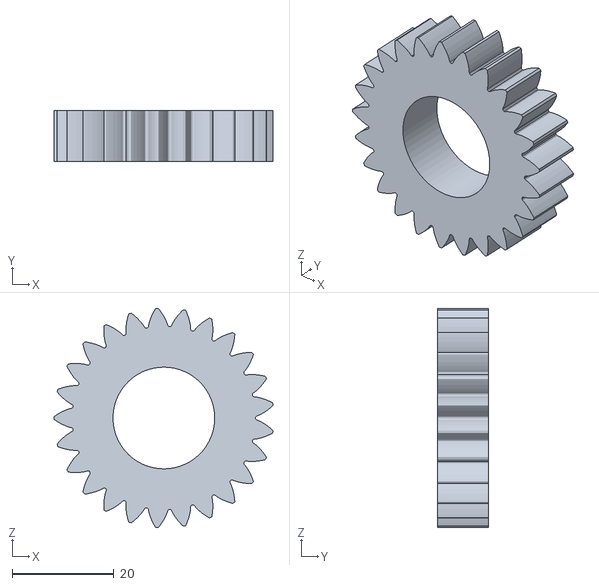
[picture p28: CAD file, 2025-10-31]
Documentos/Entregable N°9/Piezas stl/A_Engranaje_25.stl
43.1 x 10.0 x 43.1

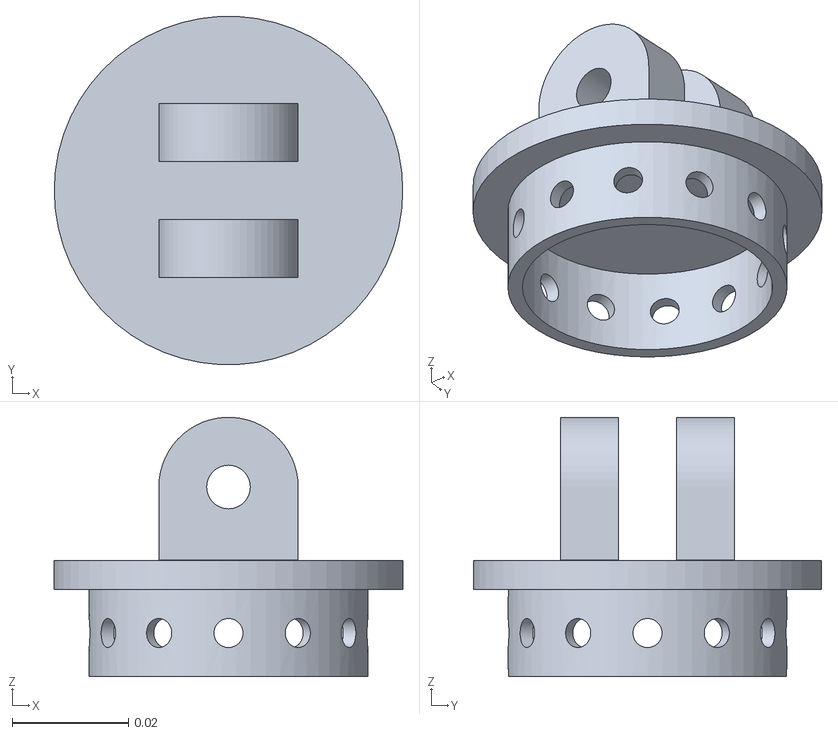
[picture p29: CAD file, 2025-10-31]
Documentos/Entregable N°9/Piezas stl/P_rotador_mango.stl
0.06 x 0.0599 x 0.0446

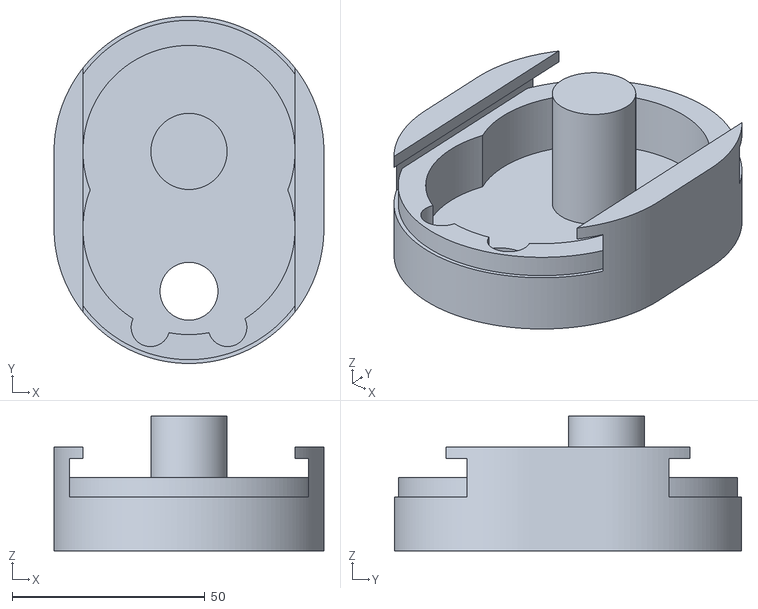
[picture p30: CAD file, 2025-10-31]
Documentos/Entregable N°9/Piezas stl/R_ratchet.stl
70.0 x 90.0 x 35.0

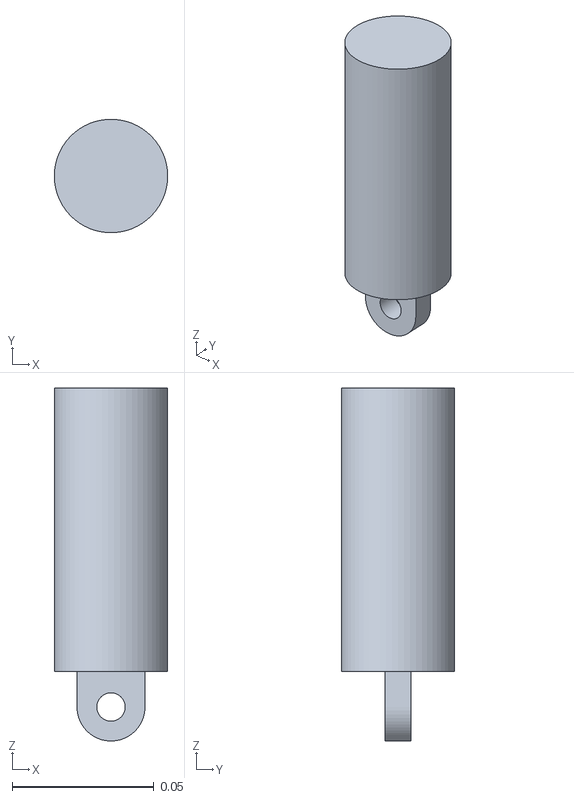
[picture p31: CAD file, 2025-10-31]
Documentos/Entregable N°9/Piezas stl/P_mango.stl
0.04 x 0.0399 x 0.124

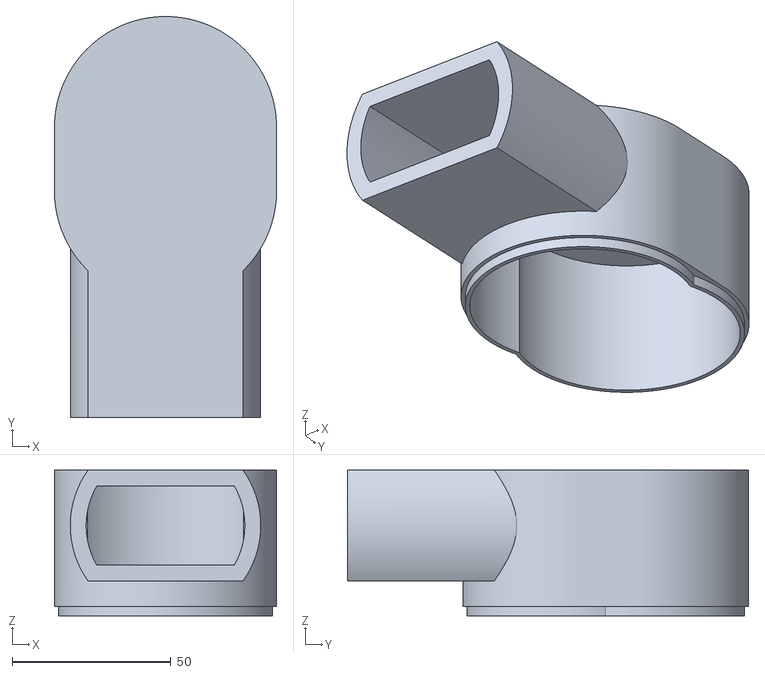
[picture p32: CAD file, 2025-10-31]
Documentos/Entregable N°9/Piezas stl/R_conector_barra.stl
70.0 x 126.4 x 46.0

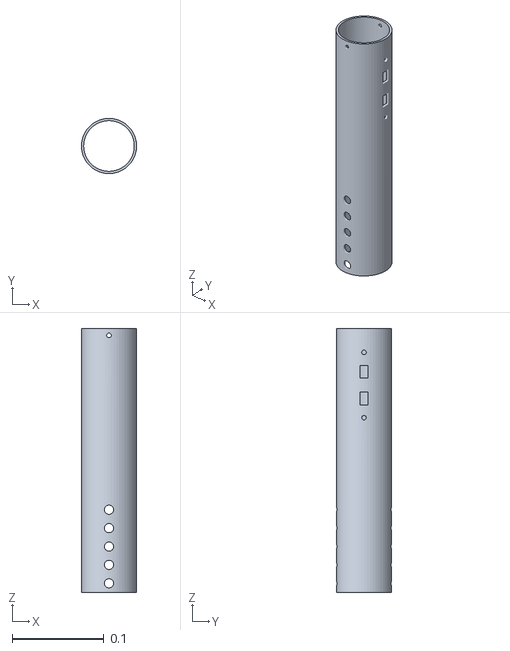
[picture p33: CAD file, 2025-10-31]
Documentos/Entregable N°9/Piezas stl/P_union_superior.stl
0.06 x 0.06 x 0.287

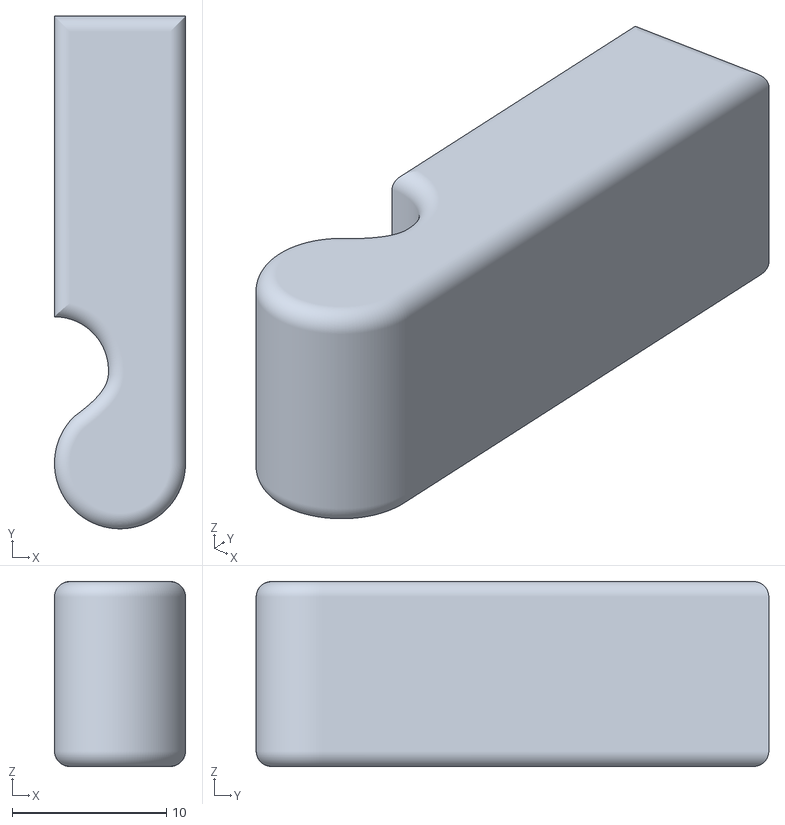
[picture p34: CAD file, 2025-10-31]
Documentos/Entregable N°9/Piezas stl/R_Barra direccion.stl
8.50 x 33.2 x 12.0

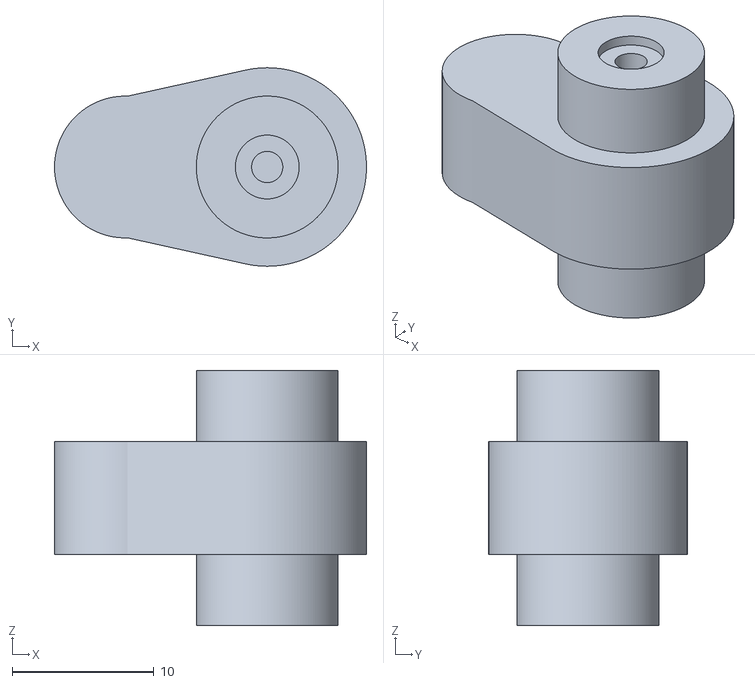
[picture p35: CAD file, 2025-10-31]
Documentos/Entregable N°9/Piezas stl/Servo Horn.stl
22.0 x 14.0 x 18.0

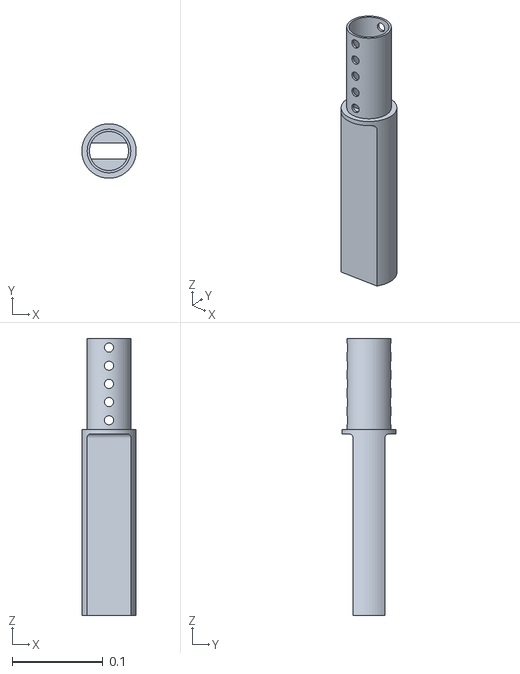
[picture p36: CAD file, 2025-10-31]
Documentos/Entregable N°9/Piezas stl/P_union_inferior.stl
0.06 x 0.0599 x 0.305

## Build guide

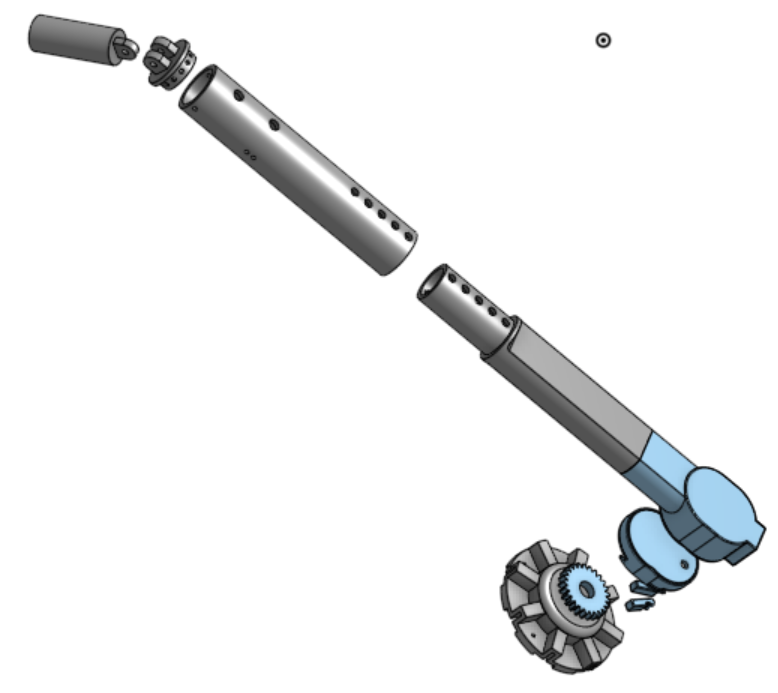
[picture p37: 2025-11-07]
Documentos/Entregable N°10/Fabricación digital/Vista explosiva.png

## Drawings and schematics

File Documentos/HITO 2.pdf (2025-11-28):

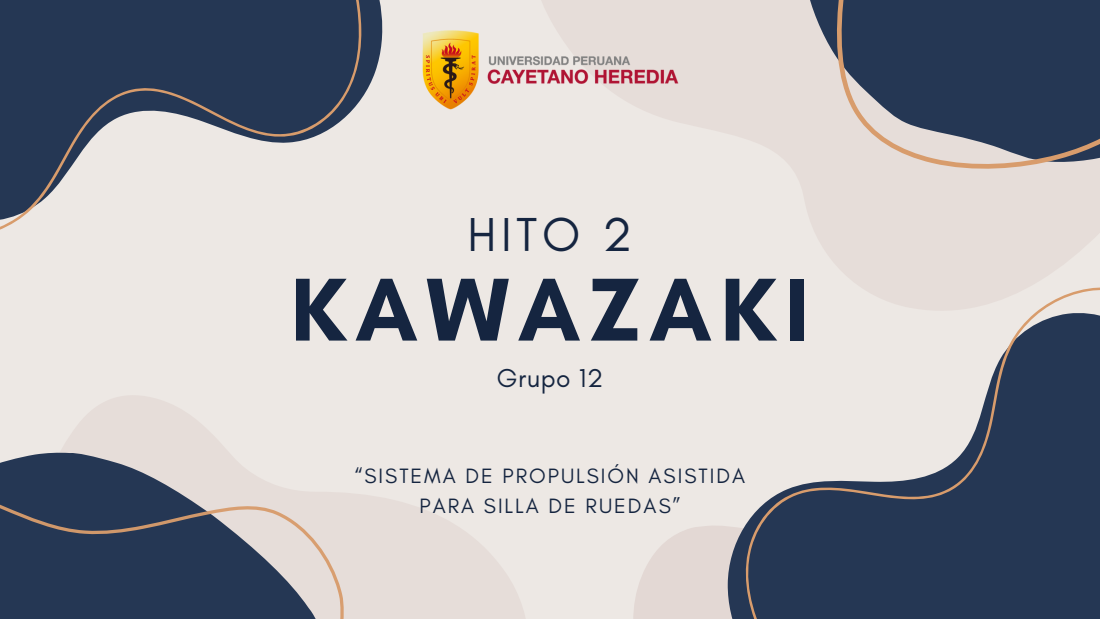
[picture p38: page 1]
Grupo 12; KAWAZAKI; HITO 2; “SISTEMA DE; PROPULSIÓN ASISTIDA

PARA SILLA DE RUEDAS”

# EL EQUIPO

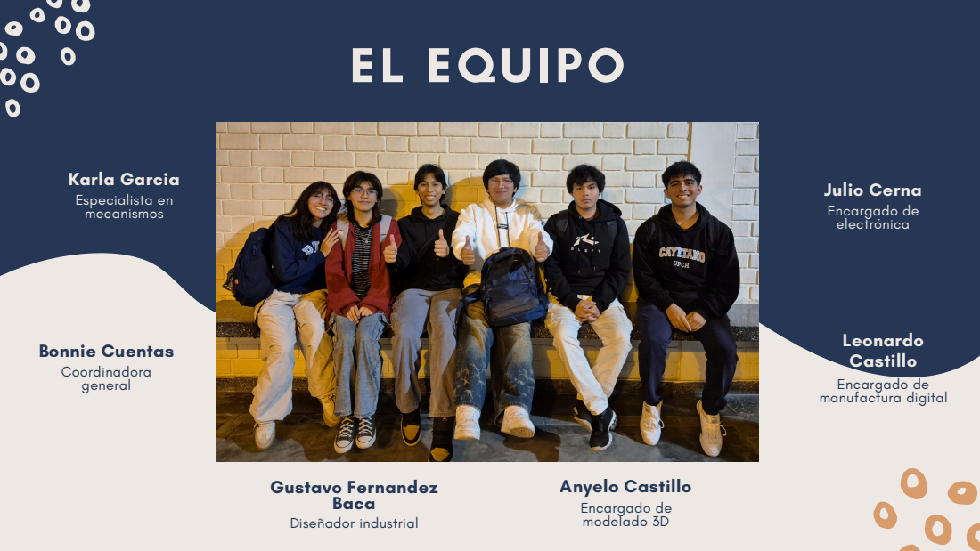
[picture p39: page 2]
Bonnie Cuentas Coordinadora general; Julio Cerna Encargado de electrónica; Karla Garcia Especialista en mecanismos; Gustavo Fernandez Baca Diseñador industrial; Anyelo Castillo Encargado de modelado 3D; Leonardo Castillo; Encargado de manufactura digital

# PROBLEMÁTICA

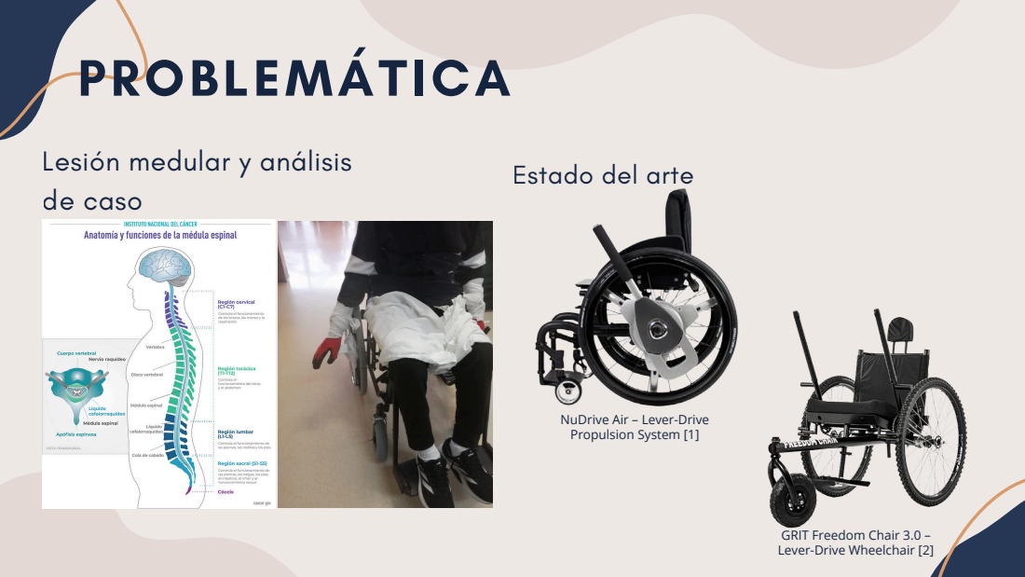
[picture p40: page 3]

Lesión medular y análisis
de caso

Estado del arte

NuDrive Air – Lever-Drive
Propulsion System [1]

GRIT Freedom Chair 3.0 –
Lever-Drive Wheelchair [2]

# SOLUCIÓN

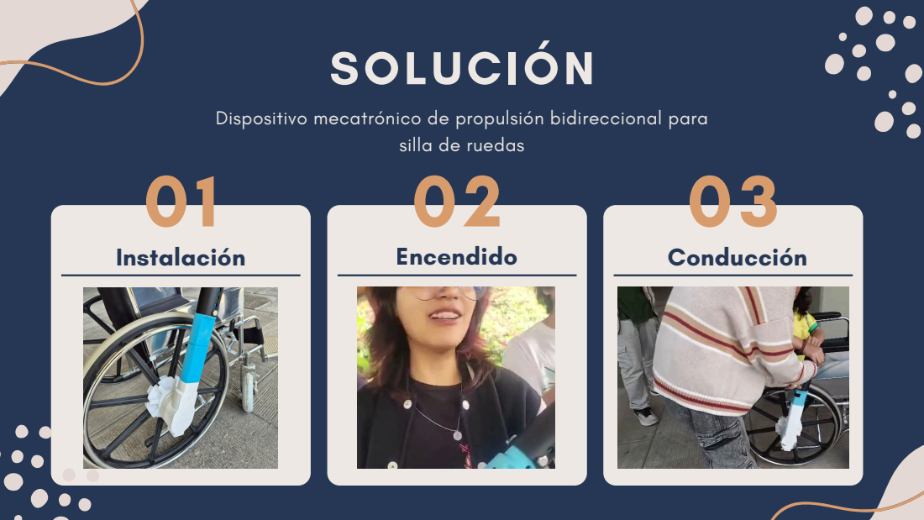
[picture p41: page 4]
Instalación; Encendido; Conducción

Dispositivo mecatrónico de propulsión bidireccional para

silla de ruedas

# BOCETOS

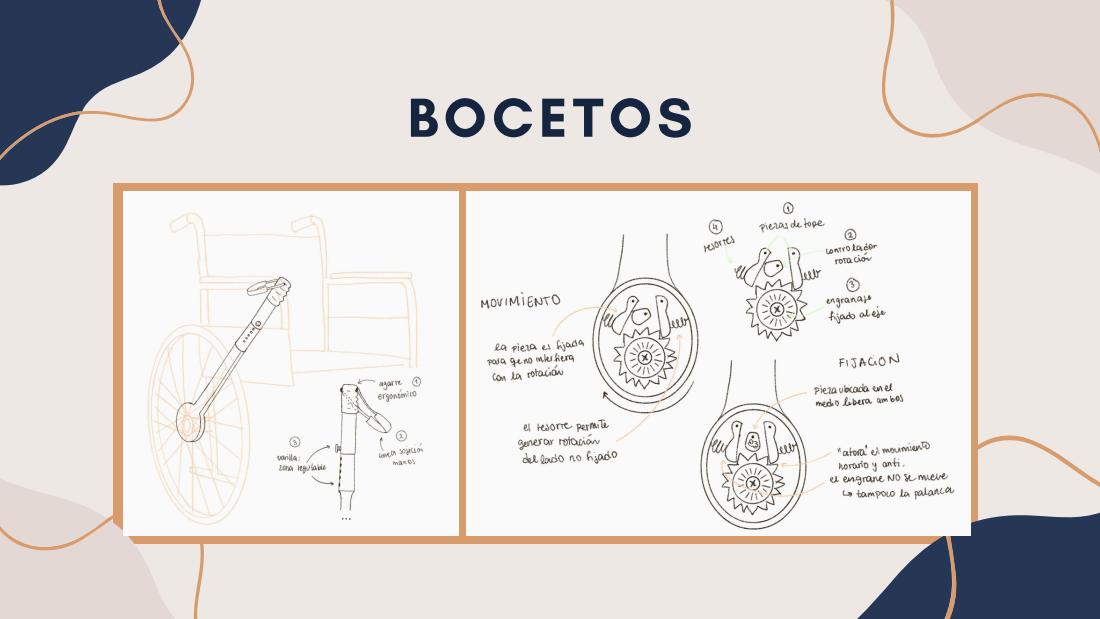
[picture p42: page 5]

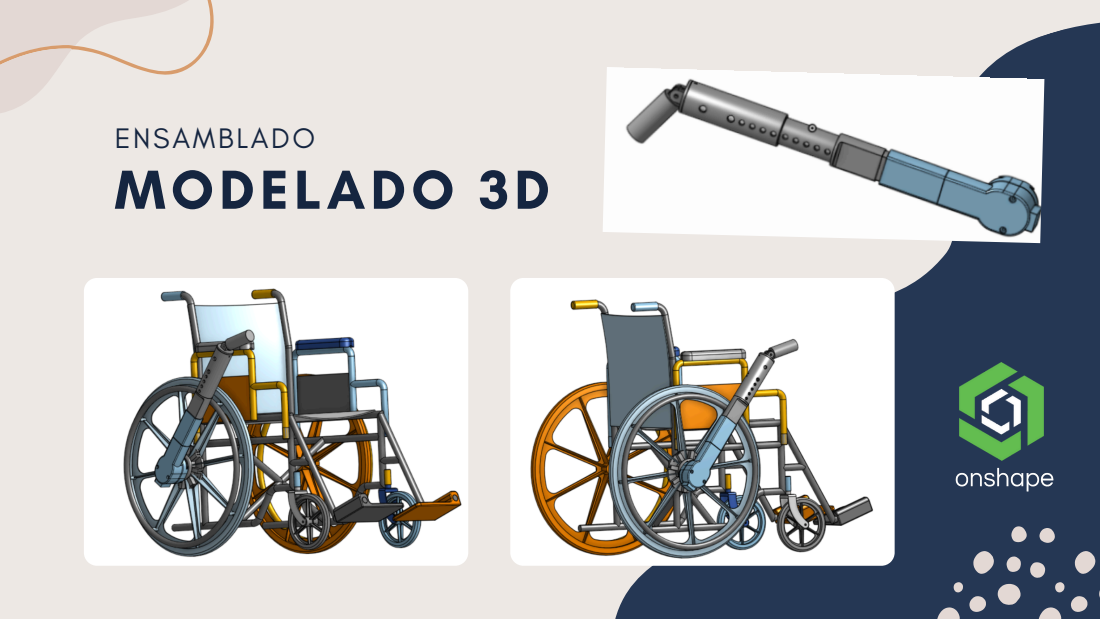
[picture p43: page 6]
MODELADO; ENSAMBLADO

## DE FLUJO

## DIAGRAMA

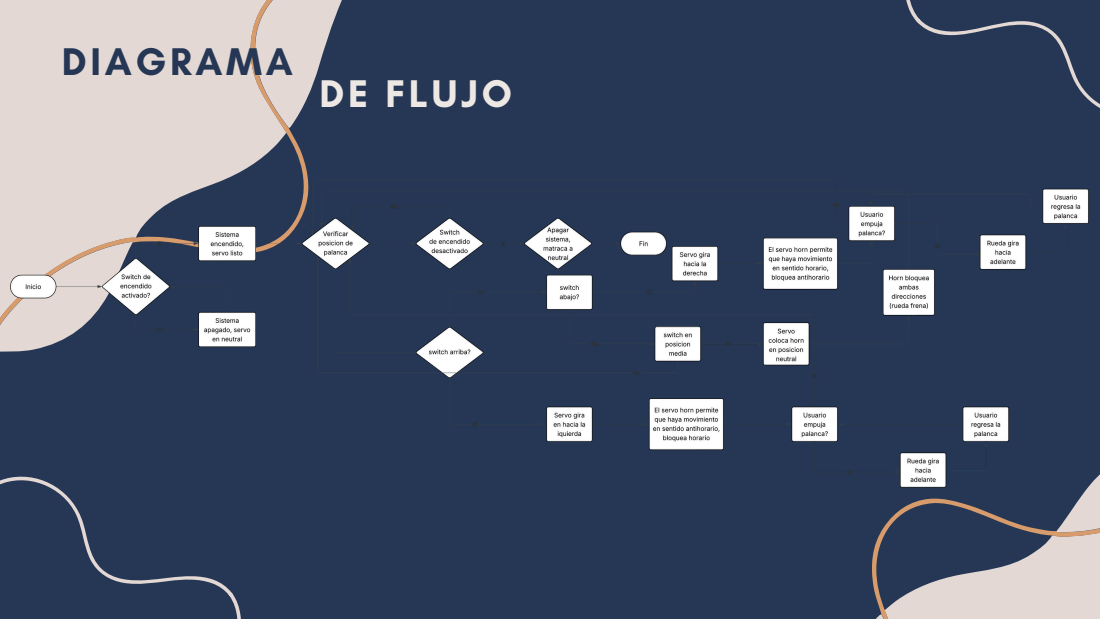
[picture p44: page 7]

# DIAGRAMA ESQUEMÁTICO

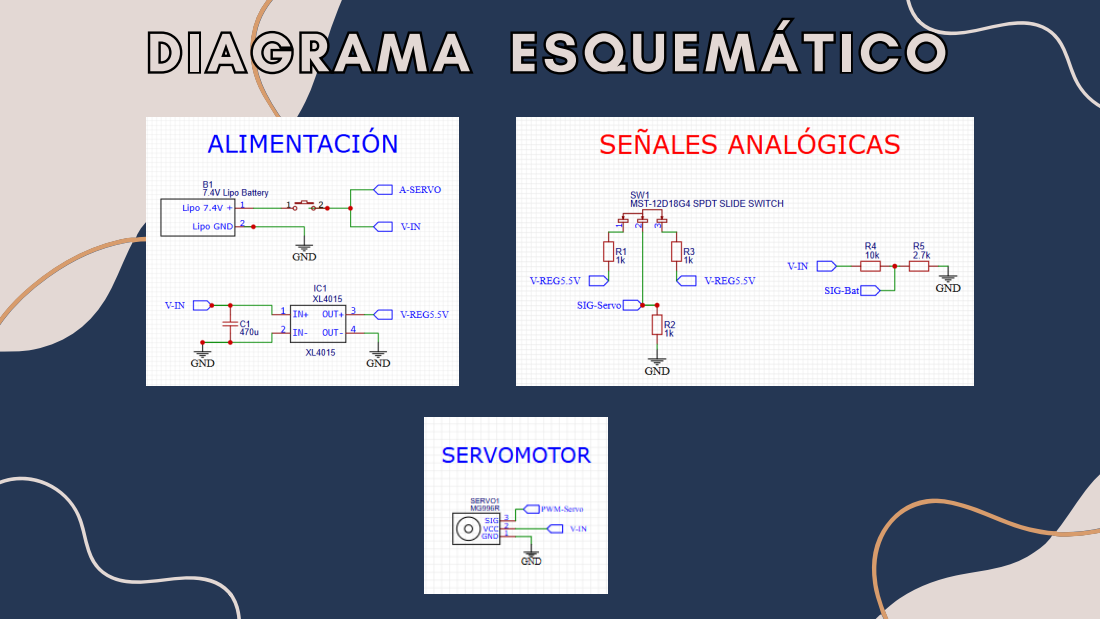
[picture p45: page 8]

# DIAGRAMA ESQUEMÁTICO

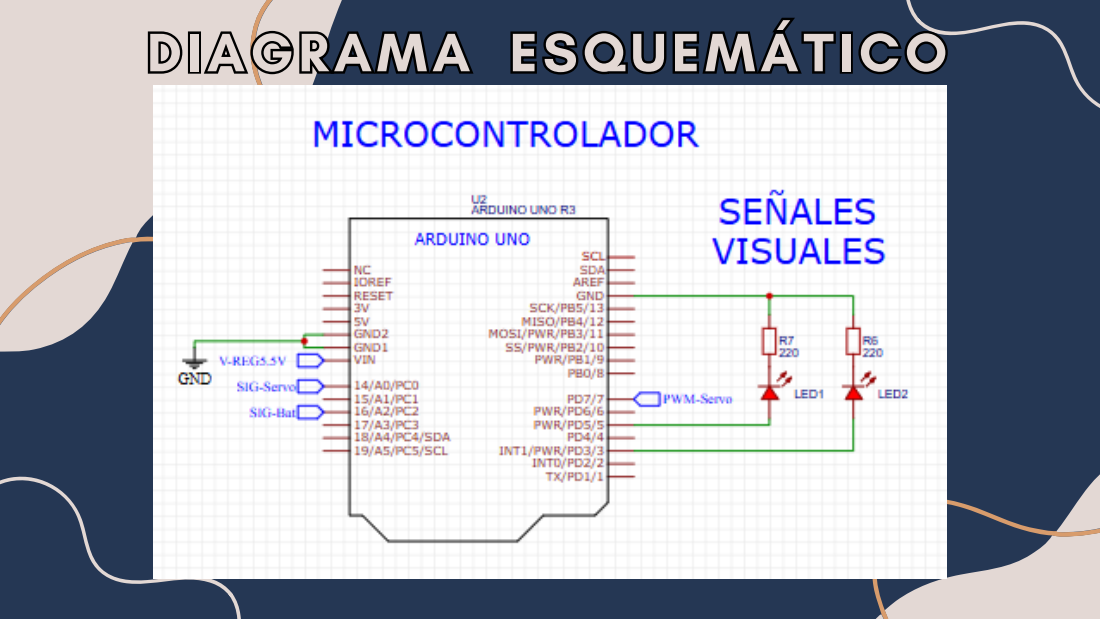
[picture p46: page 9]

# ENSAMBLADO

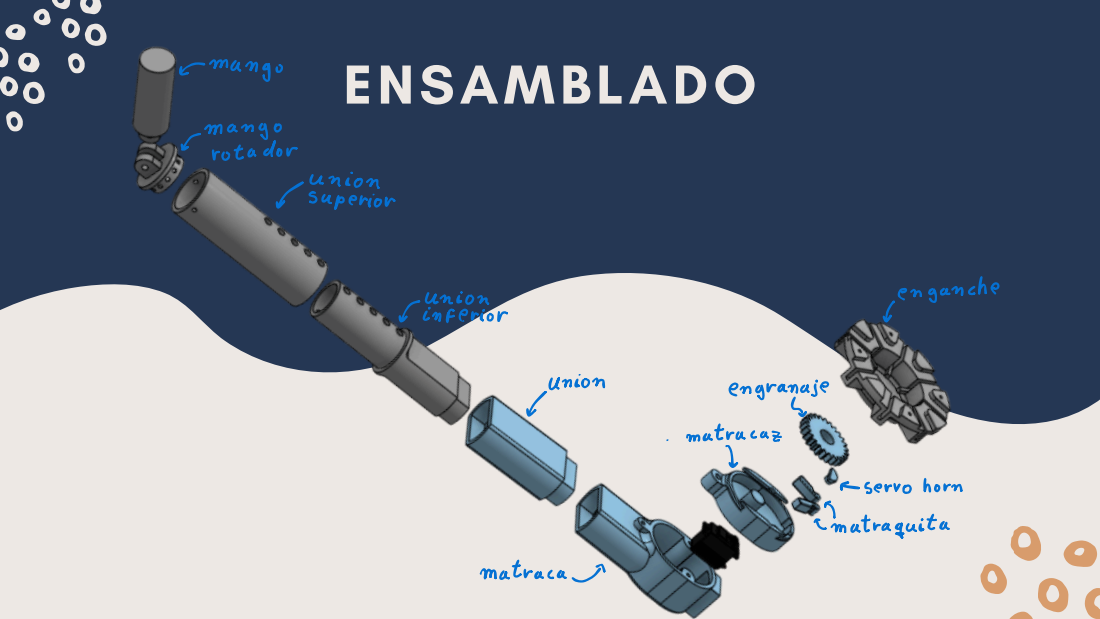
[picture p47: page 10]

## COMPONENTES

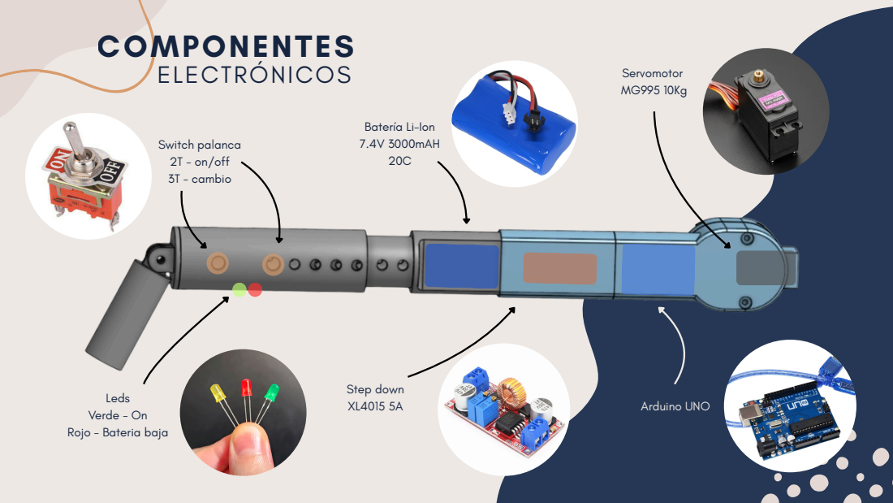
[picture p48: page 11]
ELECTRÓNICOS; Servomotor MG995 10Kg; Switch palanca 2T - on/off 3T - cambio; Batería Li-Ion 7.4V 3000mAH 20C; Arduino UNO; Step down XL4015 5A

Leds
Verde - On
Rojo - Bateria baja

# PROTOTIPO

## INTEGRADO

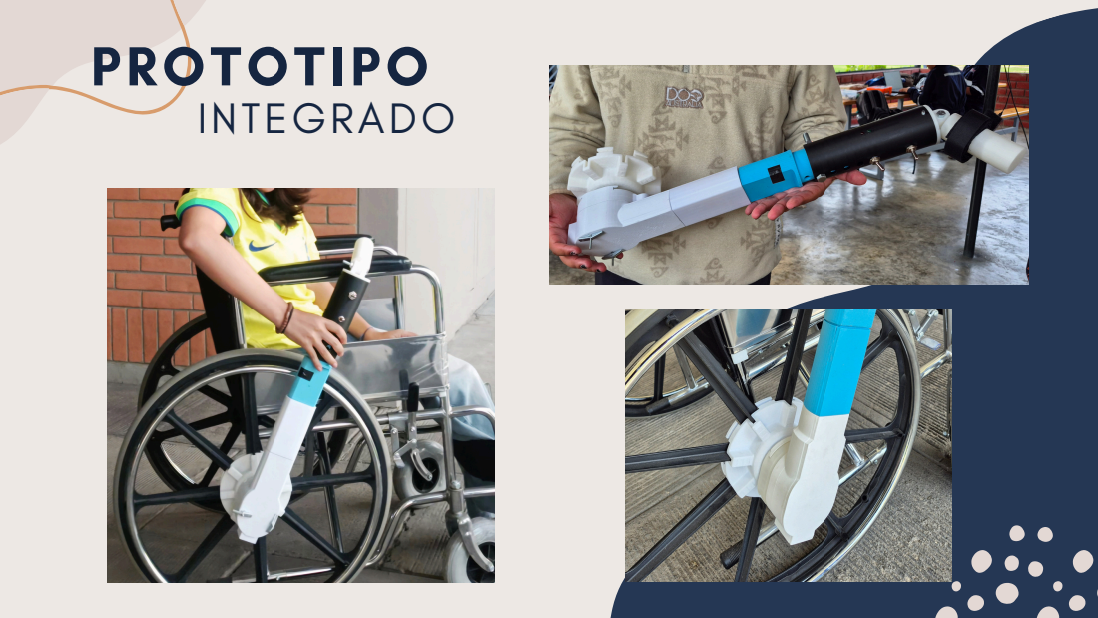
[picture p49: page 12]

# FUNCIONAL

## VIDEO

Mecanismo ratchet

## PROBLEMAS Y MEJORAS

Engranaje y enganche; Resistencia palanca; Corriente estable; grosor; considerable

Para evitar problemas debido a la fuerza ejercida por el
usuario la palanca debe tener buena resistencia mecánica

Se debe estabilizar la corriente
por los picos del servo

En engranaje fue realizado con
MDF en corte laser y fue
atornillada al encaje.

Se realizaron encajes con un
reforzaron las uniones con pernos

Se empleó una batería de
7.4–8.4 V y se integró un step-
down de 5 A para asegurar
una alimentación estable.

# RESULTADOS


# PRESUPUESTO:

1x step down: S/.9.00; Material: MDF S/. 20.00; Electronica; Estructural

2x switch: S/.13.00 1x Arduino: S/.18.00

Material: PLA
Gramaje total: 781.6 gr
Horas de impresión: 21h56m
Costo: S/. 60.00

2x leds: S/.0.60 1x Batería: S/.38.00

1x servomotor: S/.23.00 Cableado y resistencias: S/.5.00 Total: S/. 106.60

# LIMITACIONES

el codigo; Implementación; Diseño

El servohorn original del sistema
ratchet no se adaptaba
correctamente al modelado 3D, por
lo que se rediseñó su geometría

El prototipo fallo en pruebas de
resistencias, asi que decidimos
reforzar el diseño

El servomotor a veces generaba
picos elevados, por lo que
mejoramos el sistema de
alimentacion y algunos detalles en

En la unión con la rueda, también
fue necesario ajustar los encajes
para garantizar un montaje más
estable y seguro.

# PRUEBAS Y TESTEOS



# MUCHAS GRACIAS

# REFERENCIAS


[1] | NuDrive | Air | – | Lever-Drive | Propulsion | System, | André | Viger, | 2024. | Disponible | en:
https://andreviger.com/en/manual-wheelchair-accessories/790-nudrive-air-wheelchair-propulsion-leversystem.html
[2] GRIT Freedom Chair 3.0 – Lever-Drive Wheelchair, GRIT USA, 2024. Disponible en: https://www.gogrit.us/gritfreedom-chair-3-0/

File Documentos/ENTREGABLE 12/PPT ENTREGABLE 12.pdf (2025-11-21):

# ENTREGABLE 12:


Plan de uso

# Contexto de uso


El dispositivo busca mejorar la autonomía del
paciente Palacios aprovechando su movilidad
residual en brazos y hombros. Se usará en el Instituto
Nacional de Rehabilitación y en espacios domésticos
adaptados. Aunque un cuidador puede ayudar al
inicio, el objetivo es que el paciente pueda
desplazarse por sí mismo usando la palanca en sus
actividades diarias y de rehabilitación.

# PERFIL DE USUARIO


El paciente Palacios tiene una lesión medular C3 con cuadriplejia completa, pero conserva movilidad parcial en brazos y hombros gracias a la ZPP, lo que le permite hacer movimientos de empuje. No controla el tronco ni las piernas y depende de cuidadores para la mayoría de actividades. Cognitivamente está totalmente lúcido y muy motivado por recuperar autonomía. Poder desplazarse por sí mismo representaría una mejora funcional importante y

un beneficio emocional significativo.

# Análisis de tareas


Categoría | Tareas Críticas (importantes para la seguridad) | Tareas No Críticas (no afectan seguridad inmediata)

Primer uso | -Fijar correctamente el mecanismo ratchet al eje. - Colocar bien las correas de sujeción. | - Posicionar la silla. - Ajustar el largo de la palanca. - Capacitación inicial.

Uso cotidiano | - Verificar la posición del selector. - Cambiar correctamente la dirección del selector. - Activar modo inmóvil para detenerse. | - Ejecutar el movimiento de palanca para avanzar. - Retirar las correas al finalizar.

Mantenimiento | - Revisar estado de piezas. - Lubricar el mecanismo ratchet. - Inspeccionar engranajes y topes. | — Tareas menores de limpieza o ajuste que no comprometen la seguridad inmediata.

# Criterios de exito

FUNCIONAMIENTOBASICO Activatracciónen≤2intentosypermite avanzarsinayuda.; FACILIDADDEUSO Elcambiodemodomedianteelswitch debehacerseenmenosde1minuto.; SEGURIDAD; Sintrabasniriesgos(0fallasy0lesiones).; SATISFACCIONDELUSUARIO Calificación≥4/5encomodidad,claridaddel usoyexperienciageneral.

gracias
